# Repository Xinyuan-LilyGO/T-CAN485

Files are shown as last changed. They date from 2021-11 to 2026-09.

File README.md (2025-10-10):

<!--
 * @Description: None
 * @version: V1.0.0
 * @Author: LILYGO_L
 * @Date: 2023-09-11 16:13:14
 * @LastEditors: LILYGO_L
 * @LastEditTime: 2024-06-24 11:24:56
 * @License: GPL 3.0
-->
<h1 align = "center">T-CAN485</h1>

## **English | [中文](./README_CN.md)**

## Version iteration:
| Version | Update date |
| :---: | :---: |
| T-CAN485 | - |

## PurchaseLink

| Product | SOC |  FLASH  |  PSRAM | Link |
| :---: | :---: |:---: | :---: | :---: |
| T-CAN485 | ESP32 | 4M | - | [AliExpress](https://pt.aliexpress.com/item/1005003624034092.html)  |

## Directory
- [**English | 中文**](#english--中文)
- [Version iteration:](#version-iteration)
- [PurchaseLink](#purchaselink)
- [Directory](#directory)
- [Describe](#describe)
- [Preview](#preview)
  - [PCB board](#pcb-board)
  - [Details](#details)
- [Module](#module)
  - [1.MCU](#1mcu)
  - [2. RS485](#2-rs485)
  - [3. CAN](#3-can)
  - [4. Booster chip](#4-booster-chip)
- [QuickStart](#quickstart)
  - [Examples Support](#examples-support)
  - [Arduino](#arduino)
    - [ESP32](#esp32)
  - [firmware download](#firmware-download)
- [PinOverview](#pinoverview)
- [RelatedTests](#relatedtests)
- [FAQ](#faq)
- [Project](#project)
- [Information](#information)
- [DependentLibraries](#dependentlibraries)

## Describe

The T-CAN485 is a core board developed based on the ESP32 chip, featuring 1 CAN bus and 1 RS485 device. It supports high voltage input (5V-12V) and is equipped with a programmable WS2812 RGB LED bead. Additionally, it supports TF card functionality.

## Preview

### PCB board

<p align="center" width="100%">
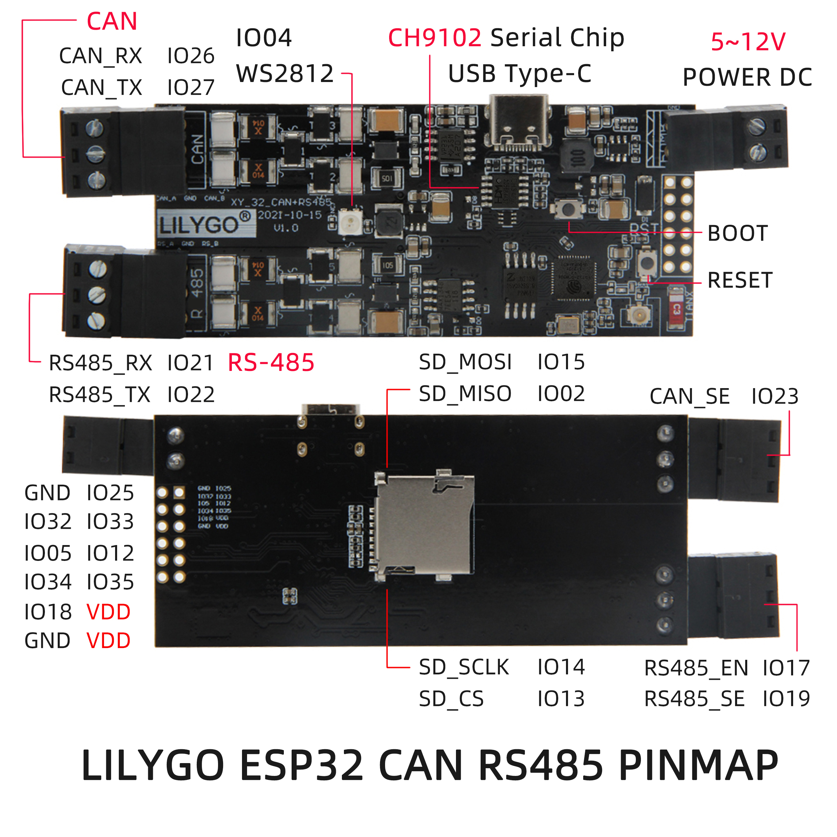
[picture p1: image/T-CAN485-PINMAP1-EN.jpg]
    
</p>

### Details

<p align="center" width="100%">
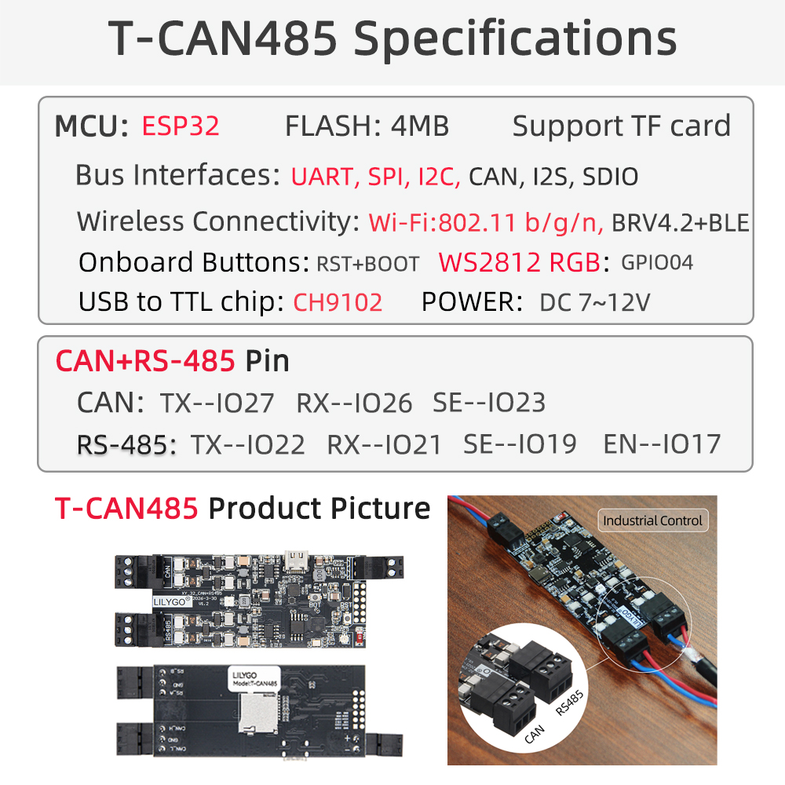
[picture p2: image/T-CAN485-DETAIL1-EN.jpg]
    
</p>

## Module

### 1.MCU

* Chip: ESP32
* FLASH: 4M
* For more details, please visit[Espressif ESP32 Datashee](https://www.espressif.com.cn/sites/default/files/documentation/esp32_datasheet_en.pdf)

### 2. RS485

* Chip: MAX13487EESA+
* Bus communication protocol: UART

### 3. CAN

* Chip: SN65HVD231
* Bus communication protocol: TWAI

### 4. Booster chip

* Chip: ME2107A50M5G

## QuickStart

### Examples Support

| Example | Support IDE And Version| Description | Picture |
| ---  | ---  | --- | --- |
| [CAN](./examples/CAN) | `[Arduino IDE][arduino_esp32_v3.0.1]` |  |  |
| [Original Test](./examples/Original_Test) |`[Arduino IDE][arduino_esp32_v3.0.1]` | Product factory original testing |  |
| [RS485_WS2812B](./examples/RS485_WS2812B) |`[Arduino IDE][arduino_esp32_v3.0.1]` |  |  |
| [SD](./examples/SD) |`[Arduino IDE][arduino_esp32_v3.0.1]` |  |  |
| [WIFI_HTTP_Download_File](./examples/WIFI_HTTP_Download_File) |`[Arduino IDE][arduino_esp32_v3.0.1]` |  |  |
| [WS2812B_Blink](./examples/WS2812B_Blink) |`[Arduino IDE][arduino_esp32_v3.0.1]` |  |  |

| Firmware | Description | Picture |
| ---  | ---  | --- |
| [Original Test V1.0.0](./firmware/[T-CAN485_V1.0][Original_Test]_firmware_V1.0.0) | Original |  |

### Arduino
1. Install[Arduino](https://www.arduino.cc/en/software),Choose installation based on your system type.

2. Open the "example" directory within the project folder, select the example project folder, and open the file ending with ".ino" to open the Arduino IDE project workspace.

3. Open the "Tools" menu at the top right -> Select "Board" -> "Board Manager." Find or search for "esp32" and download the board files from the author named "Espressif Systems." Then, go back to the "Board" menu and select the development board type under "ESP32 Arduino." The selected development board type should match the one specified in the "platformio.ini" file under the [env] section with the header "board = xxx." If there is no corresponding development board, you may need to manually add the development board from the "board" directory within your project folder.

4. Open menu bar "[File](image/6.png)" -> "[Preferences](image/6.png)" ,Find "[Sketchbook location](image/7.png)"  here,copy and paste all library files and folders from the "lib" folder in the project directory into the "libraries" folder in this directory.

5. Select the correct settings in the Tools menu, as shown in the table below.

#### ESP32
| Setting | Value |
| :---: | :---: |
| Board | ESP32 Dev Module |
| Upload Speed | 921600 |
| CPU Frequency | 240MHz (WiFi) |
| Flash Mode | QIO |
| Flash Size | 4MB (32Mb) |
| Core Debug Level | None |
| PSRAM | Disable |
| Arduino Runs On | Core 1 | 

6. Select the correct port.

7. Click "<kbd>[√](image/8.png)</kbd>" in the upper right corner to compile,If the compilation is correct, connect the microcontroller to the computer,Click "<kbd>[→](image/9.png)</kbd>" in the upper right corner to download.

### firmware download
1. Open the project file "tools" and locate the ESP32 burning tool. Open it.

2. Select the correct burning chip and burning method, then click "OK." As shown in the picture, follow steps 1->2->3->4->5 to burn the program. If the burning is not successful, press and hold the "BOOT-0" button and then download and burn again.

3. Burn the file in the root directory of the project file "[firmware](./firmware/)" file,There is a description of the firmware file version inside, just choose the appropriate version to download.

<p align="center" width="100%">
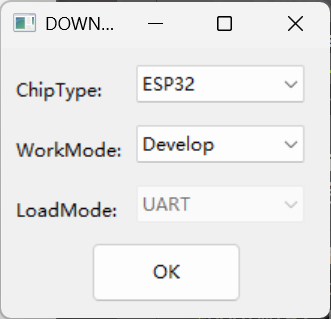
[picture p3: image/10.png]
    
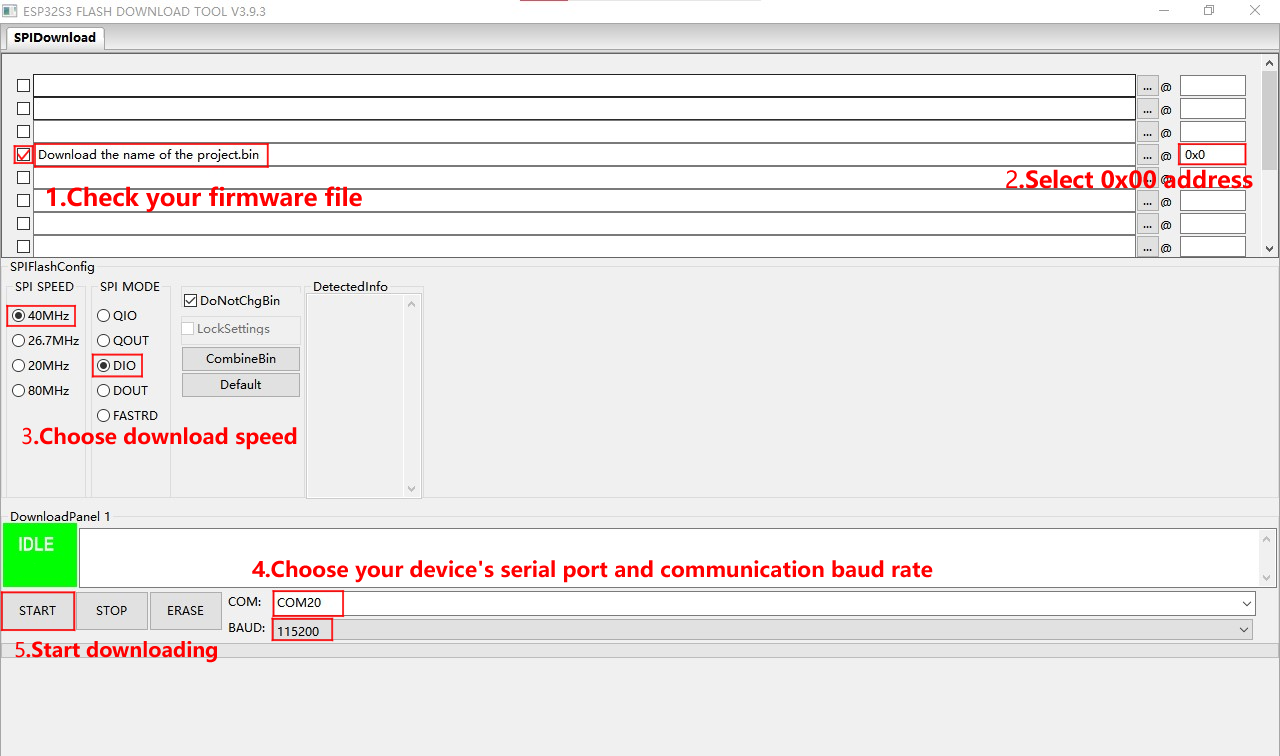
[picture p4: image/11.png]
    
</p>

## PinOverview

| RS485 PIN  | ESP32 PIN|
| :---: | :---:|
| TX | IO22 |
| RX | IO21 |
| CALLBACK | IO17 |
| EN | IO9 |

| WS2812 PIN  | ESP32 PIN|
| :---: | :---:|
| DATA | IO4 |

| ME2107 PIN  | ESP32 PIN|
| :---: | :---:|
| EN | IO16 |

| SD PIN  | ESP32 PIN|
| :---: | :---:|
| MISO | IO2 |
| MOSI | IO15 |
| SCLK | IO14 |
| CS | IO13 |

## RelatedTests

## FAQ

* Q. After reading the above tutorials, I still don't know how to build a programming environment. What should I do?
* A. If you still don't understand how to build an environment after reading the above tutorials, you can refer to the [LilyGo-Document](https://github.com/Xinyuan-LilyGO/LilyGo-Document) document instructions to build it.

<br />

* Q. Why does Arduino IDE prompt me to update library files when I open it? Should I update them or not?
* A. Choose not to update library files. Different versions of library files may not be mutually compatible, so it is not recommended to update library files.

<br />

* Q. Why is my board continuously failing to download the program?
* A. Please hold down the "BOOT-0" button and try downloading the program again.

## Project
* [T-CAN485](./project/T-CAN485.pdf)

## Information
* [MAX13487EESA+](./information/MAX13487EESA+.pdf)
* [SN65HVD231](./information/SN65HVD231.pdf)

## DependentLibraries
* [FastLED-3.7.0](https://github.com/FastLED/FastLED)

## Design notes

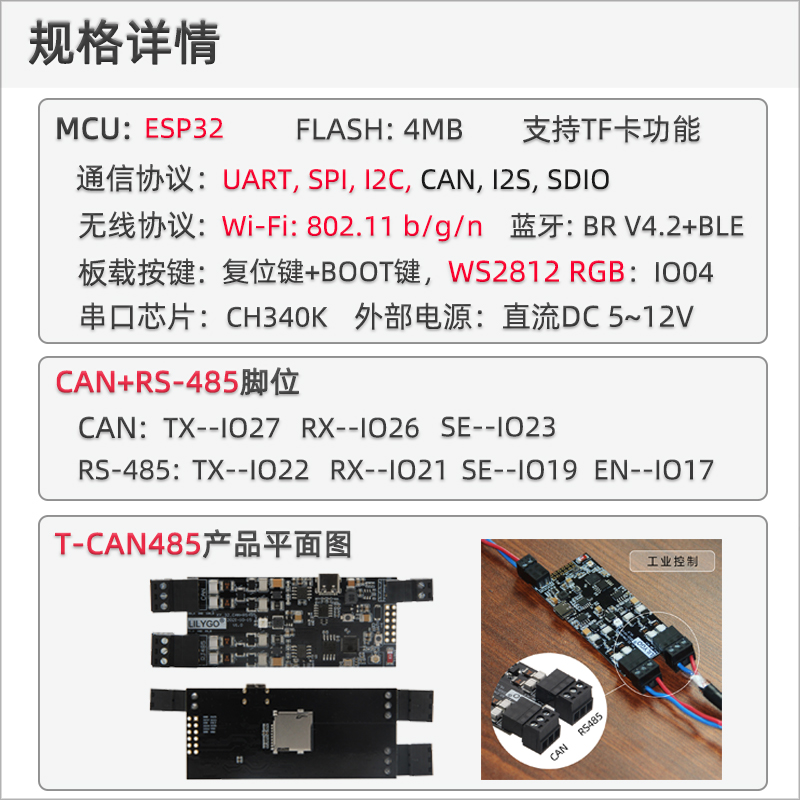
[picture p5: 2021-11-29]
image/T-CAN485-DETAIL-CN.jpg

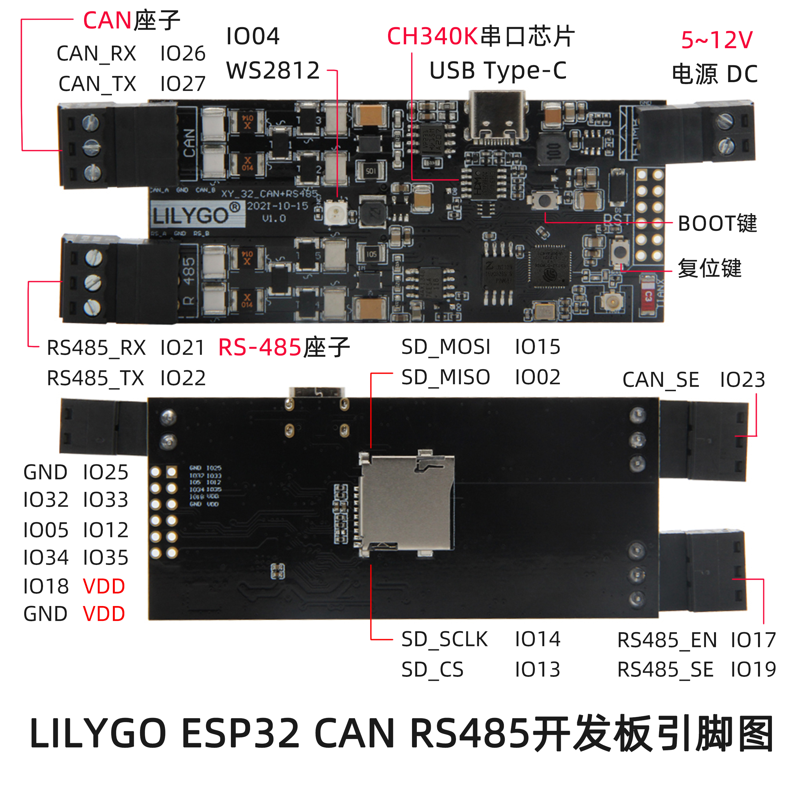
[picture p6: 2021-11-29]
image/T-CAN485-PINMAP-CN.jpg

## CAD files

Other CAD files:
project/T-CAN485.dwg

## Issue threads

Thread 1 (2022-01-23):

Documentation: Wrong URL in README.md for Arduino Board install

milen100, 2022-01-23:
URL should be fixed to : https://raw.githubusercontent.com/espressif/arduino-esp32/gh-pages/package_esp32_index.json .
In the REAME.md now there is missing slash which cases URL access to fail when the URL is added in Arduino Preferences page.

Roman-Jordan, 2022-01-23:
Good call on this, It would be nice to identify procedures to load ones software on the module.
  * Press and hold `reset` and `boot` button.
  * Release the `Reset` button, and then the `boot` button.

LilyGO, 2022-01-24:
Thank you for your suggestion

Roman-Jordan, 2022-01-28:
Are you using PlatformIO? I use the esp32 one..

crow1170, 2022-01-28:
I'm trying to use the Arduino IDE, and while an Esp32 Dev board exists, it's throwing an error in the compile step:

> In file included from c:\$$$\documents\arduinodata\packages\esp32\tools\xtensa-esp32-elf-gcc\gcc8_4_0-esp-2021r2\xtensa-esp32-elf\include\c++\8.4.0\memory:63,
                 from C:\$$$\Documents\ArduinoData\packages\esp32\hardware\esp32\2.0.2\cores\esp32\Esp.cpp:24:
c:\$$$\documents\arduinodata\packages\esp32\tools\xtensa-esp32-elf-gcc\gcc8_4_0-esp-2021r2\xtensa-esp32-elf\include\c++\8.4.0\bits\allocator.h:46:10: fatal error: bits/c++allocator.h: No such file or directory
 #include <bits/c++allocator.h> // Define the base class to std::allocator.
          ^~~~~~~~~~~~~~~~~~~~~
compilation terminated.
exit status 1
Error compiling for board ESP32 Dev Module.

I expected the Boards Manager would have prevented such an error, but I'm not even sure that everything would work if that error is resolved.

The board doesn't behave any differently when I perform the reset/boot pattern you mentioned, except to send some text over the Serial Monitor:

> rst:0x1 (POWERON_RESET),boot:0x3 (DOWNLOAD_BOOT(UART0/UART1/SDIO_REI_REO_V2))
waiting for download

Closed 2022-01-24.

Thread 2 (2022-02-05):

modbus rs485/can to mqtt software on T-CAN485

xjustbmw, 2022-02-05:
Hi there,

I purchased the t-can485 board for the following project:

I'm trying to achieve rs485/canbus to mqtt converter over wifi ( and optional if there is the possibility to add rj45 wired lan extension to it)

Anybody can help me with this software ? Should be similar to Friendtrol's GW-1205B interface.
Read/write a few registers over mqtt protocol. Config the initial wifi credentials in AP mode.

Im interested in buying at least 200 boards like this if the software works.
I can also support this software development if necessary.

Many thanks,
Adrian

Roman-Jordan, 2022-02-05:
That does not sound to difficult 🤔 .. Fork and drop me an invite.

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

Roman-Jordan, 2022-02-06:
As this does not seem to be an issue with the board. Would you mind closing this and opening it up in a fork?

Closed 2022-02-06.

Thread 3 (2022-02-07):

Arduino IDE set up

antoineTK, 2022-02-07:
Hi team!

I wanted to make sure I was doing the right things setting the Arduino IDE

1- As described in readme file: add https://raw.githubusercontent.com/espressif/arduino-esp32/gh-pages/package_esp32_index.json

2- Restart IDE

3- In board manager look up esp32 and download latest version of esp32 by Espressif Systems

4- When building and uploading choose "ESP32 Arduino --> ESP32-Dev Module"

antoineTK, 2022-02-07:
If I do it this way and I try building "Freenove_WS2812_Lib_for_ESP32" example sketches I get

In file included from C:\Users\Antoine\Documents\Arduino\libraries\Freenove_WS2812_Lib_for_ESP32\examples\Rainbow\Rainbow.ino:1:
C:\Users\Antoine\Documents\Arduino\libraries\Freenove_WS2812_Lib_for_ESP32\src/Freenove_WS2812_Lib_for_ESP32.h:35: warning: "RMT_DEFAULT_CONFIG_TX" redefined
 #define RMT_DEFAULT_CONFIG_TX(gpio, channel_id)      \

In file included from C:\Users\Antoine\Documents\Arduino\libraries\Freenove_WS2812_Lib_for_ESP32\src/Freenove_WS2812_Lib_for_ESP32.h:18,
                 from C:\Users\Antoine\Documents\Arduino\libraries\Freenove_WS2812_Lib_for_ESP32\examples\Rainbow\Rainbow.ino:1:
C:\Users\Antoine\AppData\Local\Arduino15\packages\esp32\hardware\esp32\2.0.2/tools/sdk/esp32/include/driver/include/driver/rmt.h:87: note: this is the location of the previous definition
 #define RMT_DEFAULT_CONFIG_TX(gpio, channel_id)      \

In file included from C:\Users\Antoine\Documents\Arduino\libraries\Freenove_WS2812_Lib_for_ESP32\src\Freenove_WS2812_Lib_for_ESP32.cpp:12:
C:\Users\Antoine\Documents\Arduino\libraries\Freenove_WS2812_Lib_for_ESP32\src\Freenove_WS2812_Lib_for_ESP32.h:35: warning: "RMT_DEFAULT_CONFIG_TX" redefined
 #define RMT_DEFAULT_CONFIG_TX(gpio, channel_id)      \

In file included from C:\Users\Antoine\Documents\Arduino\libraries\Freenove_WS2812_Lib_for_ESP32\src\Freenove_WS2812_Lib_for_ESP32.h:18,
                 from C:\Users\Antoine\Documents\Arduino\libraries\Freenove_WS2812_Lib_for_ESP32\src\Freenove_WS2812_Lib_for_ESP32.cpp:12:
C:\Users\Antoine\AppData\Local\Arduino15\packages\esp32\hardware\esp32\2.0.2/tools/sdk/esp32/include/driver/include/driver/rmt.h:87: note: this is the location of the previous definition
 #define RMT_DEFAULT_CONFIG_TX(gpio, channel_id)      \

In file included from C:\Users\Antoine\Documents\Arduino\libraries\Freenove_WS2812_Lib_for_ESP32\src\Freenove_WS2812_Lib_for_ESP32.cpp:12:
C:\Users\Antoine\Documents\Arduino\libraries\Freenove_WS2812_Lib_for_ESP32\src\Freenove_WS2812_Lib_for_ESP32.cpp: In member function 'bool Freenove_ESP32_WS2812::begin()':
C:\Users\Antoine\Documents\Arduino\libraries\Freenove_WS2812_Lib_for_ESP32\src\Freenove_WS2812_Lib_for_ESP32.h:53:5: error: no match for 'operator=' (operand types are 'rmt_config_t' and '<brace-enclosed initializer list>')
     }
     ^
C:\Users\Antoine\Documents\Arduino\libraries\Freenove_WS2812_Lib_for_ESP32\src\Freenove_WS2812_Lib_for_ESP32.cpp:26:11: note: in expansion of macro 'RMT_DEFAULT_CONFIG_TX'
  config = RMT_DEFAULT_CONFIG_TX(pin, rmt_chn);
           ^~~~~~~~~~~~~~~~~~~~~
In file included from C:\Users\Antoine\Documents\Arduino\libraries\Freenove_WS2812_Lib_for_ESP32\src\Freenove_WS2812_Lib_for_ESP32.h:18,
                 from C:\Users\Antoine\Documents\Arduino\libraries\Freenove_WS2812_Lib_for_ESP32\src\Freenove_WS2812_Lib_for_ESP32.cpp:12:
C:\Users\Antoine\AppData\Local\Arduino15\packages\esp32\hardware\esp32\2.0.2/tools/sdk/esp32/include/driver/include/driver/rmt.h:81:3: note: candidate: 'rmt_config_t& rmt_config_t::operator=(const rmt_config_t&)'
 } rmt_config_t;
   ^~~~~~~~~~~~
C:\Users\Antoine\AppData\Local\Arduino15\packages\esp32\hardware\esp32\2.0.2/tools/sdk/esp32/include/driver/include/driver/rmt.h:81:3: note:   no known conversion for argument 1 from '<brace-enclosed initializer list>' to 'const rmt_config_t&'
C:\Users\Antoine\AppData\Local\Arduino15\packages\esp32\hardware\esp32\2.0.2/tools/sdk/esp32/include/driver/include/driver/rmt.h:81:3: note: candidate: 'rmt_config_t& rmt_config_t::operator=(rmt_config_t&&)'
C:\Users\Antoine\AppData\Local\Arduino15\packages\esp32\hardware\esp32\2.0.2/tools/sdk/esp32/include/driver/include/driver/rmt.h:81:3: note:   no known conversion for argument 1 from '<brace-enclosed initializer list>' to 'rmt_config_t&&'
exit status 1
Erreur de compilation pour la carte ESP32 Dev Module

Roman-Jordan, 2022-02-07:
I have no idea at this moment but might be able to poke at it a bit later
today. Gotta get in the line for the homeless shelter early if a want a
place to stay.. so.. we shall see if I get time. Hahaha, your only valuable
in america if you do drugs and have kids. But if you spend your time
learning skills that no one understands.. you deserve to be homeless cause
your less than poop.

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

Roman-Jordan, 2022-02-07:
Sorry, just woke up when I had seen this. I will have some time this
evening sometime to poke at this if you want.

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

antoineTK, 2022-02-07:
No worries man, I hope your day is going ok!

I was thinking I might use FastLED if I can not figure this out

Roman-Jordan, 2022-02-07:
Nice. If you got time for a call. I can walk you through it.

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

Roman-Jordan, 2022-02-07:
42427257fourTwo Drop me a text when your ready.

LilyGO, 2022-02-09:
Hello, it can be seen from the log that the WS2812 library is not installed;
1) First compile the flash program from the example to test whether the basic environment is completed.
2) Install all required dependencies
- https://github.com/Freenove/Freenove_WS2812_Lib_for_ESP32
- https://github.com/miwagner/ESP32-Arduino-CAN

antoineTK, 2022-02-09:
The library was installed but I was getting it from the T-CAN485 repo. Getting it from the repo you linked worked for me, thank you!

In the board selection, can you confirm the default parameters are correct?

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

antoineTK, 2022-02-09:
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

LilyGO, 2022-02-10:
There is no problem with your parameter settings.

LilyGO, 2022-02-10:
FLASH MODE please select DIO

antoineTK, 2022-02-14:
@LilyGO any ideas?

Closed 2022-02-09.

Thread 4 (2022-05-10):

CAN bus continuously publishes and blocks the programme

raul-riera-imatia, 2022-05-10:
Hello, good morning!

I have a problem with the CAN bus.
I'm trying the example code found in example/Arduino/CAN
Although the bus should publish at 1000ms intervals, the bus publishes continuously and blocks the program. It never reaches line 89.
Can you help me? Do you know what is wrong?

Thank you very much for your help.

LilyGO, 2022-09-05:
There may be failures caused by unsuccessful sending. It is recommended that you try connecting the cable before powering on.

dalathegreat, 2023-04-02:
For anyone still having issues with CAN, I have a repository set up here that uses both CAN and Modbus RTU at the same time on the LilyGo Hardware: https://github.com/dalathegreat/BYD-Battery-Emulator-For-Gen24

Closed 2024-07-10.

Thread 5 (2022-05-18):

Tutorial

hanusek, 2022-05-18:
Hello.
I bought LILYGO ESP32 CAN RS485 and take it from the box. I would like to upload to it an example program but I haven't any information. I need a basic tutorial - on how to get started.
I have a problem. Arduino IDE did not recognize the T-CAN485 board (VID: 1A86 PID: 7522).

LilyGO, 2022-06-27:
1. Install ESP32 board support
2. Connect the USB, select the port
3. Click Upload

newdamage1, 2024-07-20:
It is more complicated than three steps. The Arduino IDE asks for the board; This board is not listed as an option, esp32 selections error about missing files.

We don't expect a step-by-step for beginners, but your effort at decent documentation would be appreciated by those who spend money on your products.

danishzd, 2025-07-08:
I am having trouble setting up one that I just bought, My computer does not detect any hardware connection and the board has rapidly switching lights when its plugged in. What am i missing?

lewisxhe, 2025-07-09:
Is the CH9102 driver installed? You should be able to see a COM device in the Windows Device Manager.

lewisxhe, 2025-07-09:
Is it convenient to shoot a video?
, the steps are as follows:
1. Open the computer device manager
2. Insert the USB
3. Check if there is a device in the Port list

lewisxhe, 2025-07-09:
Device Manager doesn't even respond? Refreshing the device doesn't work?

danishzd, 2025-07-09:
No, strangely it doesn’t do a thing, not even a sound

lewisxhe, 2025-07-10:
OK. Then it is damaged. Normally it will recognize the USB and see the USB device in the device manager. If you have just purchased it, please contact the dealer for after-sales service!

lewisxhe, 2025-07-15:
I have received your video and I have already talked to them. They should have arranged the shipment for you.

Closed 2022-06-27.

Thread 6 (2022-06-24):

USB Type-C Connection didn't see from Arduino-IDE Ports

Peerahongw, 2022-06-24:
Dear everyone,

How can I communicate or upload program from Arduino-IDE?

Thanks

LilyGO, 2022-06-27:
1. Install ESP32 board support
2. Connect the USB, select the port
3. Click Upload

Closed 2022-06-27.

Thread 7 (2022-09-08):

[CAN] Example for Arduino not working

hanusek, 2022-09-08:
Hello @LilyGO
I have two TTGO T-CAN485 boards (v1.0 and v1.1).
I'm trying to run the [canbus](https://github.com/Xinyuan-LilyGO/T-CAN485/tree/main/example/Arduino/CAN) example. But I have a problem with it. The Board not sends and receive any can bus frames. I have only `TIME -> CAN send done` in the serial-log.

1.
I found weird things in the schematic and [code](https://github.com/Xinyuan-LilyGO/T-CAN485/blob/07886ab0acd5bdf81f059a37994451682eaa761b/example/Arduino/CAN/config.h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).
**CAN_TX in the schematic == GPIO27
CAN_RX in the schematic == GPIO26**
but in **config.h**:
```
#define CAN_TX_PIN 26
#define CAN_RX_PIN 27
```
It is a bug?

2. I connect my board to the USB port (power + data).
Did the board require a power supply to work (5 VDC)?
Because in example code we have it:
```
pinMode(PIN_5V_EN, OUTPUT);
digitalWrite(PIN_5V_EN, HIGH);
```

Please help.

LilyGO, 2022-09-09:
Try using this example.

`https://github.com/Xinyuan-LilyGO/T-CAN485/tree/main/example/PlatfromIO/CAN`
The thing to pay attention to is whether the chip is a V3 version. Q&A in the readme suggests that there is a register that needs to be modified. The modified place is
`https://github.com/Xinyuan-LilyGO/T-CAN485/blob/07886ab0acd5bdf81f059a37994451682eaa761b/example/PlatfromIO/CAN/lib/ESP32-Arduino-CAN/src/CAN.c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`

Closed 2022-09-26.

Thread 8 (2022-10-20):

RS485 pin layout unclear + antennae interface

mortennlund, 2022-10-20:
Its not immediately clear whats the port layout of the RS485 connector A and B (or CAN for that matter). See image:
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

Also what antennae interface is used? MHF3 or MHF4?
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

Best Morten

LilyGO, 2022-10-24:
The middle interface is GND. You try to connect A to the following port. B continues above. Reverse it if communication fails.
The place in the red circle in this picture is the external antenna. Can not be used.
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

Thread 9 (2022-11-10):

Error in config.h from can.ino example

MENIER, 2022-11-10:
Hello,
It seems to have an error in your example :(https://github.com/Xinyuan-LilyGO/T-CAN485/tree/main/example/Arduino/CAN) in config.h:
```
#define CAN_TX_PIN 26
#define CAN_RX_PIN 27
```
and in CAN.ino
```
CAN_cfg.tx_pin_id = GPIO_NUM_27;
CAN_cfg.rx_pin_id = GPIO_NUM_26;
```

Llgok, 2024-06-24:
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

Please use the latest version branch Arduino_ESP32_v3.0.1 as the main reference.

Closed 2024-06-24.

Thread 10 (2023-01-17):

missing documentation wifi connector

wiensmit, 2023-01-17:
i can't find this anywhere in the documentation, what type of mhf connector fits this board for the wifi antenna.

Rojasoterom, 2024-01-06:
> i can't find this anywhere in the documentation, what type of mhf connector fits this board for the wifi antenna.

Do you find it? I try but i can't

HBK1, 2024-01-06:
External wifi antenna can not be used.
Se https://github.com/Xinyuan-LilyGO/T-CAN485/issues/8#issuecomment-1288286752

Closed 2024-07-10.

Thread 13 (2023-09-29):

Problem with uploading application when inputs/outputs are connected

balouken, 2023-09-29:
What is the best way to program this board while everything is connected?
Some Reset/boot button procedure? I've tested some stuff, but don't have success

Llgok, 2024-07-10:
@balouken
Please specifically describe the problem you encountered (serial port output or programming upload error log).

Closed 2024-08-21.

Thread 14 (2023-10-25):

Expected usage of the bus GND pins?

bobemoe, 2023-10-25:
The middle pins of the CAN and RS485 bus connectors are labelled AGND and DGND respectively on the schematic and are not connected directly to GND. It appears they connect to GND through a RC filter of some sort and are also connected to the transient voltage suppression components respectively for each bus.

What is the expected use of this pin. I cant work out if:

1. Is this pin REQUIRED to be connected to external ground for the voltage protection components to work properly or could it be left unconnected?
2. Is this is a suitable GND point to connect the shield of the bus cables to. I understand the shield should be connected directly to ground and only at one end of the bus. This would be a very convenient location but given that its not directly connected to GND and I cant find any documentation on this pin, I'm unsure if this is a correct use.

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
https://github.com/Xinyuan-LilyGO/T-CAN485/blob/main/doc/schematic.pdf

bobemoe, 2024-02-14:
Another possibility here would be, when connecting to an OBD port which has 2 ground pins, signal and chassis:
The signal ground would connect to the middle GND pin along with the CAN hi/low lines, and the chassis ground would connect to the power GND along with the supply voltage line?
I guess then the shield would connect to `chassis ground`.

Really if one of the designers of this board, or someone experienced in this, could shed some light on the intention of these middle GND pins that would be really helpful. Thanks.

Llgok, 2024-06-24:
> Another possibility here would be, when connecting to an OBD port which has 2 ground pins, signal and chassis: The signal ground would connect to the middle GND pin along with the CAN hi/low lines, and the chassis ground would connect to the power GND along with the supply voltage line? I guess then the shield would connect to chassis ground.
>
> Really if one of the designers of this board, or someone experienced in this, could shed some light on the intention of these middle GND pins that would be really helpful. Thanks.

AGND is used for the anti-static shielded ground interface of the CAN bus. DGND is used for the anti-static shielded ground interface of the RS485. The function of the two GNDs is to prevent static electricity and protect the circuit board.
@bobemoe

Closed 2024-06-24.

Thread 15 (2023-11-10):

How to change IER parameter of CAN controller?

ajaykoppisetty, 2023-11-10:
I got the chip with v3. In the read me file, it was mentioned to update the IER parameter for v3 for CAN bus to work. How and where to change it? Please help.

aliman22, 2024-01-18:
by hans from https://www.cnx-software.com/2021/12/20/ttgo-t-can485-an-esp32-board-with-rs485-can-bus-interfaces/
Just to save someone else 3 hours of googling trying to figure out what this cryptic instruction actually means:

Depending on the ESP32 chip, the CAN controller register IER parameter needs to be changed. If it is a V3 version chip, you can use 0xEF, otherwise, use 0xFF.

You can change the value from 0xef to 0xff on line 229 of the file CAN.c in the ESP32-Arduino-CAN library:

MODULE_CAN->IER.U = 0xef; //ESP32 V3 0XEF    ESP32 NOT V3 0XFF

Do note it is set to 0xef by default, so if you have a V3 ESP32 you do not need to change anything.

Closed 2024-07-10.

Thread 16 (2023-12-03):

RS485 ESPHome connect issue

Yocee84, 2023-12-03:
Hi! I cant use this panel. Please share correct esphome setup.

I use this:

substitutions:
  devicename: *******
  description: ********
  entity_prefix: *******

esphome:
  name: "${devicename}"
  comment: "${description}"

esp32:
  board: esp32dev
  framework:
    type: arduino

# Enable logging
logger:
  level: DEBUG
  baud_rate: 0

web_server:
  port: 80

# Enable Home Assistant API
api:
  encryption:
    key: "*****************************************"

ota:

wifi:
  networks:
  - ssid: !secret wifi_ssid
    password: !secret wifi_password
  - ssid: *********
    password: ************
  reboot_timeout: 0.05h

  # Enable fallback hotspot (captive portal) in case wifi connection fails
  ap:
    ssid: "*****2"
    password: "**********"

captive_portal:

light:
  - platform: neopixelbus
    type: GRB
    variant: WS2812
    pin: GPIO04
    num_leds: 1
    name: "Light"

uart:
  id: mod_bus
  tx_pin: 22
  rx_pin: 21
  baud_rate: 9600
  stop_bits: 1

modbus:
  flow_control_pin: 5
  id: heatpump_modbus

Bwooce, 2023-12-09:
Try this for some inspiration, I'm working on a homeassistant forum post to go with it. This is working for my application.

https://gist.github.com/Bwooce/7c43622dcc9bc1fbb04d7a0f1e5528df

Yocee84, 2023-12-12:
> Try this for some inspiration, I'm working on a homeassistant forum post to go with it. This is working for my application.
>
> https://gist.github.com/Bwooce/7c43622dcc9bc1fbb04d7a0f1e5528df

That's how it works for me. Thank you very much!
You should get a commission. Is there a buy me a coffee link?

Saentist, 2023-12-29:
This is how I make it to work in ESPHome with Growatt inverter

`Output` section is important obviously, without it it not work.

```yaml
# Set pins required for LilyGo T-CAN485 board
output:
  - platform: gpio
    id: ENABLE_PIN # Enable the chip
    pin:
      number: GPIO19
      inverted: true
  - platform: gpio
    id: SE_PIN # Enable autodirection
    pin:
      number: GPIO17
      inverted: true
  - platform: gpio
    id: ENABLE_5V_PIN # Enable 5V pin for RS485 chip
    pin:
      number: GPIO16
      inverted: true

# UART MODBUS configuration entry
uart:
  id: mod_uart
  rx_pin: GPIO21
  tx_pin: GPIO22
  baud_rate: 9600 # The out-of-box baud rate for my particular sensor->RS485 bridge
  stop_bits: 1
  parity: NONE
#  data_bits: 8
  debug:
    direction: BOTH
    dummy_receiver: false
    after:
      delimiter: "\n"
    sequence:
      - lambda: UARTDebug::log_string(direction, bytes);

modbus:
  id: modbus1
  uart_id: mod_uart
#  flow_control_pin: GPIO4

modbus_controller:
  - id: Growatt_MIN600TLX
    address: 0x1   ## address of the ModBUS slave device on the bus
    modbus_id: modbus1
    setup_priority: -10
```

drawlusyk, 2024-05-22:
[Archive.zip](https://github.com/Xinyuan-LilyGO/T-CAN485/files/15409245/Archive.zip)

Here are my can1 and can2 files. Connect h to h and l to l. Sends test data back and forth.

dvbit, 2024-11-01:
Just. Ought one device. I have a doubt about the connections. As far as I know a b and gnd are needed.in the board Iconnector I see just an and b on pin 20 and 21 . Where is gnd?

Sleeper85, 2025-01-11:
> Here are my can1 and can2 files. Connect h to h and l to l. Sends test data back and forth.

Thanks for sharing your examples, so you confirmed that it is necessary to enable (set to high) PIN 23 to make the CAN chip work ?

Llgok, 2025-01-13:
@Sleeper85
For using CAN, you can refer to this example：[CAN](https://github.com/Xinyuan-LilyGO/T-CAN485/blob/arduino-esp32-libs_v3.0.1/examples/CAN/CAN.ino)
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

Sleeper85, 2025-01-16:
@Llgok

Thanks this info really helped me and it works fine with ESPHome and these settings for RS485 and CAN.

```YAML
# +--------------------------------------+
# | LilyGo T-CAN485 related config       |
# +--------------------------------------+

output:
  # MAX13487E SHDN (enable RS485 chip)
  - platform: gpio
    id: RS485_SE
    pin:
      number: 19
      inverted: true # set HIGH level
  # MAX13487E RE (enable RS485 autodirection)
  - platform: gpio
    id: RS485_EN
    pin:
      number: 17
      inverted: true # set HIGH level
  # RS485 and CAN Boost power supply
  - platform: gpio
    id: CGQ_EN
    pin:
      number: 16
      inverted: true # set HIGH level
  # SN65HVD231DR RS PIN (CAN high speed mode)
  - platform: gpio
    id: CAN_SE
    pin:
      number: 23
      inverted: false # set LOW level
```

Closed 2024-07-10.

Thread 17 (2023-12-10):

Request: Docs/silkscreen for power connection noting GND/-ve is on the board edge

Bwooce, 2023-12-10:
There's not a lot of visible guidance on the T-CAN485 board for the power connection, and so I assumed you'd made it idiot proof and put it through a bridge rectifier. Yes I know, "[always read the data sheet](https://github.com/Xinyuan-LilyGO/T-CAN485/blob/main/doc/schematic.pdf)"...

It survived a reverse-polarity event due to your other good design decisions but the board silkscreen writing is obscured once the components are placed e.g. I can't read them on the delivered board, although now I *know* it says GND I can kinda read it and not OOO. So can you please:
1. Either silkscreen the bottom with the power pin polarity, or move the words out into the square in front of the connector?
2. Update your graphics showing the pins and connections to show where +ve/-ve are on these power connectors.

It would also probably be enlightening for some buyers to know these are all plugs and sockets, I thought they were weird screw connectors until I got it and looked closely. I like it, it just wasn't obvious.

lewisxhe, 2024-02-19:
Hi,

Thank you for your feedback, I have reported it to LilyGo

Closed 2024-07-10.

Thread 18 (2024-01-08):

TF Card Read/Write Documentation

Rojasoterom, 2024-01-08:
Hi, i have problems making TF Card works. I'm trying to use RS485 and SD but when i use SD.begin, RS485 data was not readed.

Lastly, i try the following program to use only TF card. But without connect to the card:

```
#include <SD.h>
#include <SPI.h>

File myFile;

void setup()
{
  Serial.begin(9600);
  Serial.print("Iniciando SD ...");
  if (!SD.begin(13)) {
    Serial.println("No se pudo inicializar");
    return;
  }
  Serial.println("inicializacion exitosa");

  myFile = SD.open("archivo.txt");//abrimos  el archivo
  if (myFile) {
    Serial.println("archivo.txt:");
    while (myFile.available()) {
    	Serial.write(myFile.read());
    }
    myFile.close(); //cerramos el archivo
  } else {
    Serial.println("Error al abrir el archivo");
  }
}

void loop()
{

}
```

Rojasoterom, 2024-01-08:
After few test, for me is works using mySD and the following begin:

```
  if (!SD.begin(13,15,2,14)) {            //T1:13,15,2,14  T2: 23,5,19,18 M5：4,23,19,18 uint8_t csPin, int8_t mosi, int8_t miso, int8_t sck
      Serial.println("initialization failed!");
      return;
    }
    Serial.println("initialization done.");
```

Closed 2024-01-08.

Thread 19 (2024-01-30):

Unusual voltage levels on RS485

bobemoe, 2024-01-30:
# Issue

We've been using these lilygo successfully for a while now using both CAN and RS232 IO and have working firmware communicating with other devices on the RS485 bus.

We've just invested in a load more of these but cant get any of them communicate using the known working firmware on our known working RS485 bus.

To diagnose we hooked up the A and B lines to the oscilloscope, and observe unusual voltage levels.

# Expected Behaviour:

This is taken from other devices communicating on the modbus, as expected, when idle both lines are near 0. When data they are inverted square signal of each other going up to about 3.3v.

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

# Actual Behaviour:

This is taken from the output of the lilygo. Seems the idle state voltage levels are high (both about 3V), and during data transmission, one line exhibits a voltage level that is not typical for RS-485 standards going up, it seems offset, and the signals never actually invert.

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

# Steps to Reproduce:

Programme lilygo to output data on the RS232 and monitor the voltage levels on both lines during idle and transmission states using a oscilloscope.

# Additional Info

Unfortunately all our original working lillygo are out in the field so we can't make a direct comparison of these ones to our known working ones.

If we connect both lines to the logic analizer then we only see data on one line, as the yellow trace above is just detected as high. I know during development with the original boards we used the logic analizer extensively and both lines were detected.

Has something changed? We've tried adding/changing termination and biasing resistors with no luck.

We have 20 of these and have tested about 5 so far all exhibiting same issue. I believe they are genuine units. Can we provide batch number or further details?

lewisxhe, 2024-02-03:
Hi @bobemoe

Can you use two T-CAN485 for transceiver loopback testing?
First check whether the hardware can work normally?
I noticed that you said the idle voltage is about 3V. Did you measure this by connecting it to another bus or not?

bobemoe, 2024-02-03:
@lewisxhe Thanks for your response. I am in the workshop Tuesday so will test two T-CAN485 then.

Idle voltage of about 3V is shown on the "Actual" traces above. It was measured directly from the RS485 pins on the lilygo with no bus connected. Similarly the "Expected" trace was taken from the RS485 pins on one of our devices (uses MAX3486 transceiver) with no bus connected. It would be interesting to observe the voltages when the bus is connected between the two devices. I will post the traces of this on Tuesday.

bobemoe, 2024-02-08:
We managed to get one of our original lilygos back from the field which game me something to compare to.

The originals are v1.0 and the new ones we have are v1.1.

I made a small test program outputting on rs495 and uploaded to both, there was a difference between the outputs on both boards, until I set PIN_5V_EN to HIGH.

Not sure why this was not needed on the old ones or what it does exactly. Not even 100% sure it was definitely the fix as we compared and changed a lot of things over the coarse of testing, but this was the only difference between the boards we observed.

Anyway the end result is we now have them working!

Is there any change logs for 1.0 to 1.1? Or any docs what PIN_5V_EN high does?

lewisxhe, 2024-02-19:
Hi, @bobemoe

thanks for your feedback

1. PIN_5V_EN is actually connected to the enable port of the ME2107A50M5G DC booster. It must be set to HIGH to power CAN and RS485.

2. I asked the designer about the difference between Rev1.0 and Rev1.1. Only the input power switching circuit was changed, and other changes were not made.

3. If 1.0 does not require the additional setting of PIN_5V_EN to HIGH, then it may be different from the previous version in that the default on state when using USB power supply is removed (this is just my confirmation based on the previous circuit of the designer who designed this PCB , as this is the case on most boards).

Closed 2024-06-24.

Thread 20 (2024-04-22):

CAN485 ESPHome using CAN

drawlusyk, 2024-04-22:
Does anyone have suggestions on using 2 CAN485 connected vi can h & l.
I have used mcp2515 in esphome successfully but can not get these working. I have them flashed and blinking the led but not send/receive of can messages between the two.
I have wires from h to h and l to l. Is any termination required?

`time:
  - platform: sntp
    on_time:
      - seconds: /5
        then: #trying variations
          - canbus.send:
              data: [0x09, 0x10, 0x11, 0x12, 0x13, 0x14, 0x15, 0x16]
          - canbus.send:
              can_id: 2
              data: [0x01, 0x02, 0x03, 0x04, 0x05, 0x06, 0x07, 0x08]
          - canbus.send: [ 0x11, 0x22, 0x33 ]    `

`canbus:
  - platform: esp32_can
    tx_pin: GPIO27
    rx_pin: GPIO26
    can_id: 1 #the second device is can_id 2
    bit_rate: 1000kbps #have also tried 250kbps
    on_frame:
    - can_id: 0 #have tried 0 as well as 1/2 for accepting from the other device
      can_id_mask: 0
      use_extended_id: false
      then:
      - lambda: |-
          std::string b(x.begin(), x.end());
          ESP_LOGD("canid 2", "%s", &b[0] );`

teunito, 2024-05-22:
Same here. Can't get CAN working with esphome and T-CAN485. My YAML looks similar to those from @drawlusyk, i'm using interval and not time.
I tried it with a 120R resistor for termination. In https://github.com/Xinyuan-LilyGO/T-CAN485/blob/main/doc/schematic.pdf on page 2 section B-2 there is a 120R resistor (RY2) between CANL and CANH. So i think there is already termination on the board? But i'm not familiar with schema drawings.

I found https://github.com/Xinyuan-LilyGO/T-CAN485/issues/16#issuecomment-1872327090 describing that Output Section is obviously. Is there something similar for CAN?

Anyone any ideas or suggestion?

Llgok, 2024-07-10:
@drawlusyk
You can refer to the code of other contributors: https://github.com/Xinyuan-LilyGO/T-CAN485/issues/16#issuecomment-2125876729

drawlusyk, 2024-07-11:
Hello. I have uploaded the code used. If this is not what you are referring to, please advise.

-Dennis

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

mackloo, 2025-02-12:
@drawlusyk Did you manage to get CAN to work with esphome?

drawlusyk, 2025-02-13:
Hello. Yes. I provided details in a previous post. Let me know if you cant find it.

-Dennis

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

teunito, 2025-02-13:
@mackloo Have a look here: [RS485 ESPHome connect issue #16](https://github.com/Xinyuan-LilyGO/T-CAN485/issues/16#top)

mackloo, 2025-02-13:
Thank you! This is probably it but now my esphome api breaks so I can't connect to it..  will test later. So you have to pull the CAN_SE pin to high if I got it correctly? I checked @drawlusyk example and copied the section about the CAN_SE PIN so that should do the trick right?

mackloo, 2025-02-14:
Solved it! For anyone else that come looking I had to put this into my .yaml file:

output:
  - platform: gpio
    id: CAN_SE
    pin:
      number: 23
      inverted: false # set LOW level

Thanks for pointing me in the right direction!

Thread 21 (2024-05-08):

How to use TF card of T-CAN485 board?

jongils, 2024-05-08:
Dear all

I'm trying to use TF card at backside of T-CAN485 board using standard library of ESP but it didn't work because this board is used unique pin map comparing standard library so could you advise me how to use TF card from this board.

jongils, 2024-05-08:
Duplicated question. I found the solution from closed issue #18 . Pin assignment should be done by GPIO number not physical pin number.

Closed 2024-05-08.

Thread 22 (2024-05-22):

how to send data from lilygo esp32 by can protocol to another lilygo esp32 by can protocol and read data on serial monitors

Abdelrahmanars91, 2024-05-22:
hello im use LILYGO esp32 can but when include library not done . this massage  Error: 13 INTERNAL: Library install failed: moving extracted archive to destination dir: library not valid

Llgok, 2024-06-24:
> hello im use LILYGO esp32 can but when include library not done . this massage Error: 13 INTERNAL: Library install failed: moving extracted archive to destination dir: library not valid

If you are using the CAN bus, switch to the arduino_esp32_v3.0.1 branch and refer to [CAN](https://github.com/Xinyuan-LilyGO/T-CAN485/blob/arduino_esp32_v3.0.1/examples/CAN/CAN.ino) example.

@Abdelrahmanars91

Closed 2024-07-10.

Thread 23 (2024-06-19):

Bluetooth turn on?

sarzyk, 2024-06-19:
Hi I have lilygo T-CAN 485 connected to my inverter Deye. It works very well.
Now I made seccond battery with jk BMS and I want to integrate it with Home Assistant.

JK BMS can connect with my phone via Bluetooth.
Is there any chance (to turn on?) communicate BMS with inverter via Bluetooth?

ThAnks

HBK1, 2024-06-19:
Check this repository: https://github.com/syssi/esphome-jk-bms

sarzyk, 2024-06-24:
Thanks. Is chance tu use the lilygo with deye inverter via modbus and jk BMS via Bluetooth in the same time?

MBRetrofit, 2025-03-30:
> Thanks. Is chance tu use the lilygo with deye inverter via modbus and jk BMS via Bluetooth in the same time?

That's the idea, to connect in the same time the battery (CAN) and the Inverter (RS485).

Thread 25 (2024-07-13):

Compile error with Arduno IDE T-CAN485

alcomys, 2024-07-13:
Hello, i want to compile the software into the Lilygo with Arduino but i got this error.

Documents\Arduino\libraries\FastLED-3.7.0\src\fastspi.h:157:23: note: '#pragma message: No hardware SPI pins defined.  All SPI access will default to bitbanged output'
  157 | #      pragma message "No hardware SPI pins defined.  All SPI access will default to bitbanged output"

Thanks

Llgok, 2024-07-22:
@alcomys
This error belongs to the FastLED-3.7.0 library and has no impact on the project compilation; it can be ignored.

Closed 2024-08-21.

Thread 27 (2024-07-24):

Factory reset TCan board

JacobsMess, 2024-07-24:
Hello, I had a working TCAN485 board but I performed a "Full Clean" in Platform IO and now when I flash firmware I no longer have wifi. the Flash states it is successful. Is there a way of restoring the TCAN485 to factory state?

Llgok, 2024-08-22:
@JacobsMess
You can upload this example [Original_Test](https://github.com/Xinyuan-LilyGO/T-CAN485/tree/arduino-esp32-libs_v3.0.1/firmware) to reset the board to factory settings.
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

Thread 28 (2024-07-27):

Compilation Error - esp_intr.h no such file or directory

nagup, 2024-07-27:
```
\Arduino\libraries\ESP32-Arduino-CAN\src\CAN.c:37:10: fatal error: esp_intr.h: No such file or directory
   37 | #include "esp_intr.h"
      |          ^~~~~~~~~~~~
compilation terminated.
exit status 1
```

Getting above error. Quite vague so was not able to determine what is actually the issue, is the header file too new, too old for this example sketch?

I have just now tried to rollback the esp32 boards by espressif to version 2.0.11. Then I commented out SD_test(); because not defined.

I am going to try replacing the initial esp_intr.h with the updated " #include "esp_intr_alloc.h" " as can be found here

**UPDATE: Cannot find the line in  CAN.c on line 37 which says #include "esp_intr.h"**

```

_esp_intr.h: No such file or directory
   37 | #include "esp_intr.h"
      |          ^~~~~~~~~~~~
compilation terminated.

exit status 1

Compilation error: esp_intr.h: No such file or directory

to overcome that error I added this to the CAN.c file:

// #include "esp_intr.h"
#include "esp_intr_alloc.h" // jimn warning depreciated #include "esp_intr.h"
```

_Originally posted by @BEMSman in https://github.com/dalathegreat/Battery-Emulator/issues/116#issuecomment-1865074235__

Llgok, 2024-07-29:
@nagup
What version of the Arduino esp32 lib are you currently using?

nagup, 2024-07-29:
> @nagup What version of the Arduino esp32 lib are you currently using?

I didn't have the Arduino library installed, only the Espressif one. I just downloaded it, restarted ArduinoIDE and tried to compile but its still failing with the same error.

I tried another example sketch which came in the zip file, called esp32can_basic, compiling it still fails with same error

Llgok, 2024-07-30:
@nagup
Arduino libraries of different versions are not compatible with each other. The "main" branch only supports Arduino lib versions below 3.0, while the "arduino-esp32-libs_v3.0.1" branch supports Arduino lib versions 3.0.1 and above. If the wrong version is selected, it will result in compilation errors.
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

Llgok, 2024-07-30:
@nagup
It looks like you want to configure and run the CAN module on the T-CAN485 device. You should try using the latest branch "arduino-esp32-libs_v3.0.1" and compile the example project [CAN](https://github.com/Xinyuan-LilyGO/T-CAN485/blob/arduino-esp32-libs_v3.0.1/examples/CAN/CAN.ino) with the esp32-libs_v3.0.1 library.
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

nagup, 2024-07-30:
@Llgok

That worked at last.

So I deleted the libraries which I pasted into the arduino libraries folder, these were called freenove, modbus and esp32 arduino CAN.

Replaced them with the libraries in the new branch you showed above.

Then I restarted arduino and opened an example in the examples folder of the arduino-esp32-libs v3.0.1 archive file and it uploaded fine.

please note I did not uninstall the arduino and espressif esp32 boards.

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

Llgok, 2024-07-31:
@nagup
Yes, please use the latest Arduino lib library examples for compilation in the future.

tejaslithium, 2025-07-06:
Compilation Error - esp_intr.h no such file or directory same again now i am facing

Closed 2024-08-21.

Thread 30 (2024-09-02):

RS485 question (A02 Sensor)

p0l0us, 2024-09-02:
Hi,
I'm trying to read ultrasonic distance sensor A02 / RS485 modbus data via T-CAN485.
https://wiki.icbbuy.com/lib/exe/fetch.php?media=developmentboard:a02-output-interfaces.pdf

But I'm not able to receive any data and my code (see below) always ends by timeout. I will appreciate any suggestions or help.

At least I would like to know `RS485_EN_PIN` and `RS485_SE_PIN` pins are for and how should I use them for reading and writing RS485 data ?
And what what `PIN_5V_EN` (pin 16) is for ?

```
	pinMode(RS485_EN_PIN, OUTPUT);
	digitalWrite(RS485_EN_PIN, HIGH);

	pinMode(RS485_SE_PIN, OUTPUT);
	digitalWrite(RS485_SE_PIN, HIGH);

	pinMode(PIN_5V_EN, OUTPUT);
	digitalWrite(PIN_5V_EN, HIGH);
```

In my code:

```
HardwareSerial UltrasoundLiquidLevelSensor::rs485(2);

void UltrasoundLiquidLevelSensor::setup()
{
	Serial.println("[UltrasoundLiquidLevelSensor] Setup...");

	this->rs485.begin(9600, SERIAL_8N1, RS485_RX_PIN, RS485_TX_PIN);

	byte GET_ADDRESS[8] = {0xFF, 0x03, 0x02, 0x00, 0x00, 0x01, 0x90, 0x6C};
	sendData(GET_ADDRESS);
	receiveData();

	delay(100);
}

void UltrasoundLiquidLevelSensor::sendData(byte *data)
{
	time = millis();
	this->rs485.write(data, 8);
	this->rs485.flush();
	delay(10);
}

void UltrasoundLiquidLevelSensor::receiveData()
{
	Serial.println("[UltrasoundLiquidLevelSensor] Receiving data...");
	byte data[8] = {0x00, 0x00, 0x00, 0x00, 0x00, 0x00, 0x00, 0x00};
	while (this->rs485.available() == 0)
	{
		Serial.print(".");
		if (millis() - time > TIMEOUT_DELAY)
		{
			Serial.println("\n[UltrasoundLiquidLevelSensor] Request Timed Out...");
			break;
		}
		delay(50);
	}
	Serial.print("\n");
	if (this->rs485.available() > 0)
	{
		this->rs485.readBytes(data, 7);
		for (int i = 0; i < 7; i++)
		{
			Serial.print(data[i], HEX);
			Serial.print(" ");
		}
		Serial.println();
	}
}

void UltrasoundLiquidLevelSensor::loop()
{
	byte GET_DISTANCE[8] = {0x01, 0x03, 0x01, 0x00, 0x00, 0x01, 0x85, 0xF6};
	sendData(GET_DISTANCE);
	receiveData();
	delay(2000);
}
```

Llgok, 2024-09-03:
@p0l0us
In the **main** branch.
1.  **RS485\_EN\_PIN**: This is the pin controlling the RS485 callback function. By default, during initialization, it is set to output a high level to disable the callback function.
2.  **RS485\_SE\_PIN**: This is the pin controlling the enable pin of the RS485 chip. By default, during initialization, it is set to output a high level to start the chip normally.
3.  **PIN\_5V\_EN**: This is the enable switch pin for the ME2107 power chip. The total power for RS485 is connected to this chip. By default, during initialization, it is set to output a high level to turn on the power switch.

In the **arduino-esp32-libs\_v3.0.1** branch:
The correct macro definitions are provided in the [pin_config.h](https://github.com/Xinyuan-LilyGO/T-CAN485/blob/arduino-esp32-libs_v3.0.1/libraries/Mylibrary/pin_config.h) file. You can refer to this file for further details.

The **main** branch is considered outdated, and future updates will be carried out in the **arduino-esp32-libs\_v3.0.1** branch. Any errors in the previous branches can be referenced by looking at the examples in the latest branch when programming. For example, you can refer to the [RS485_WS2812B.ino](https://github.com/Xinyuan-LilyGO/T-CAN485/blob/arduino-esp32-libs_v3.0.1/examples/RS485_WS2812B/RS485_WS2812B.ino) for programming examples.

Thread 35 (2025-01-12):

12v power burnt the IC

juliancuni, 2025-01-12:
Is this board 12v capable?
It was just bad luck that my board happens to be faulty?

I did programmed it, tested in my desk, usb powered, receiving CAN messages, generatiing PWM to controll a tachometer.
When I connected to 12v it popped the chip in the picture.
What is this chip?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

andrewfraley, 2025-02-06:
FWIW I was powering mine with 12V no problem for 48h or so.  Did you reverse the polarity maybe?

juliancuni, 2025-02-06:
@andrewfraley I am confident about polarity. Maybe the problem was that I tried to run it in a automotive environment. The voltage readings were some 14v.
I don't know. Maybe it was bad luck. I'll try the other board and record the whole process.
Thank you for your feedback anyway, the lilygo guys didn't bother to respond.

juliancuni, 2025-02-06:
@andrewfraley I am confident about polarity. Maybe the problem was that I tried to run it in a automotive environment. The voltage readings were some 14v.
I don't know. Maybe it was bad luck. I'll try the other board and record the whole process.
Thank you for your feedback anyway.

andrewfraley, 2025-02-15:
Mine’s been running for a week now on 12V, but seeing this prompted me to add a 1A inline fuse on the input.

juliancuni, 2025-02-15:
> input

I don't see how a fuse helps with voltage?

andrewfraley, 2025-02-16:
Just in case this thing decides to give up the ghost, mines enclosed with some batteries so I cant risk any sort of fire.

Giddy-Up224, 2025-10-06:
> [@andrewfraley](https://github.com/andrewfraley) I am confident about polarity. Maybe the problem was that I tried to run it in a automotive environment. The voltage readings were some 14v. I don't know. Maybe it was bad luck. I'll try the other board and record the whole process. Thank you for your feedback anyway.

I bet that's the issue. 12V in electronics are not always the nominal 12V of automotive circuits.

lewisxhe, 2025-10-07:
We have confirmed with the factory that U6 uses TMI3253, which supports up to 18V input, so 12V is not enough to break down the chip.

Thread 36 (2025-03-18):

Deye 50k BMS connection

Gubysh, 2025-03-18:
Hello
I need to set BMS ommunication LILYGO TTGO T-Can 485 ESP32 CAN RS-485 to deye inverter

I dont understand how to connect it

Gubysh, 2025-03-18:
Could i connect it to inverter using RS485 port on inverter board?

lewisxhe, 2025-03-24:
This board has RS485 and CAN interfaces. You need to find RS485_A and RS485_B of your device and connect these two interfaces to A+ B+ of this board. You also need to compile the code according to the protocol of your device before you can use it.

The connection diagram is probably like this

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

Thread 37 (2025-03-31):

RS485 and esphome

sobiso, 2025-03-31:
Hi,

I have strange issue, when I connect only my slave device to the bus it doesn't work. But when I also connect to the bus my computer via usb-rs485 the communication between the board and slave works and on computer I can see this communication (request and response)

My esphome configuration
```output:
  - platform: gpio
    id: ENABLE_PIN # Enable the chip
    pin:
      number: GPIO19
      inverted: true
  - platform: gpio
    id: SE_PIN # Enable autodirection
    pin:
      number: GPIO17
      inverted: true
  - platform: gpio
    id: ENABLE_5V_PIN # Enable 5V pin for RS485 chip
    pin:
      number: GPIO16
      inverted: true

uart:
  id: mod_uart
  rx_pin: GPIO21
  tx_pin: GPIO22
  baud_rate: 9600
  debug:
    direction: BOTH
    dummy_receiver: false
    after:
      delimiter: "\n"
    sequence:
      - lambda: UARTDebug::log_string(direction, bytes);

modbus:
  id: modbus1
  uart_id: mod_uart

modbus_controller:
- id: modbus_device
  address: 0x1   ## address of the Modbus slave device on the bus
  modbus_id: modbus1
  setup_priority: -10
  update_interval: 10s

sensor:
- platform: modbus_controller
  modbus_controller_id: modbus_device
  register_type: holding
  name: "ASP-215 Temerature"
  address: 0x0600    ## address of the register inside the Modbus slave device
  unit_of_measurement: "°C"
  value_type: S_WORD```

lewisxhe, 2025-04-01:
```c
switch:
  - platform: gpio
    id: ENABLE_PIN
    pin:
      number: GPIO19
      inverted: true
    restore_mode: ALWAYS_ON

  - platform: gpio
    id: SE_PIN
    pin:
      number: GPIO17
      inverted: true
    restore_mode: ALWAYS_ON
  - platform: gpio
    id: ENABLE_5V_PIN
    pin:
      number: GPIO16
      inverted: true
    restore_mode: ALWAYS_ON
```
Try adding Always open

sobiso, 2025-04-02:
I changed resistors 4k7, pull up and pull down, and it works.

lewisxhe, 2025-04-07:
Which resistor did you change? Can you share?

sobiso, 2025-04-07:
Next to MAX13486, R3 and R8. Both to 330 Ohm

Closed 2025-04-02.

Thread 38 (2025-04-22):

CAN BUS Interrupt Pin

cosmin91, 2025-04-22:
Hi, I've tried a lot of code versions, but seems like I'm not able to wake up the esp32 when I receive a new CAN message. It's probably a hardware limitation, but just want to double check if there is something that will trigger the wakeup pin on esp32 when there is can bus activity.
Thanks,
Cosmin

lewisxhe, 2025-04-23:
Do you mean esp32 in sleep mode? CAN interrupt??

cosmin91, 2025-04-23:
@lewisxhe yes, exactly.

lewisxhe, 2025-04-23:
ESP does not have a separate wake-up function for CAN

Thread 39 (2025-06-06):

RS485 and virtual serial port

CreasolTech, 2025-06-06:
Hi,
is it possible to use the module as a virtual serial port, like you can do with with
* **socat** on the main controller and
* **ser2net** in the slave module connected to a RS485 bus?

It will be useful to connect RS485 devices that do not use the standard Modbus protocol.
Thanks.
Paolo

lewisxhe, 2025-06-09:
https://github.com/espressif/arduino-esp32/blob/master/libraries/WiFi/examples/WiFiClientBasic/WiFiClientBasic.ino

https://github.com/Xinyuan-LilyGO/T-CAN485/blob/main/example/Arduino/RS485/RS485.ino

You just need to send the message received by rs485 through TCP. You can refer to these two examples.

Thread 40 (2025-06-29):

I2C pins

githubcdr, 2025-06-29:
Hi,

What PINS can I use for I2C? I tried GPIO32 and GPIO33 for SDA and SCL but that does not work.

Regards,

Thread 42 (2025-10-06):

library named incorrectly when used in PlatformIO as URL in platformio.ini `lib_deps`

Giddy-Up224, 2025-10-06:
I added this to my platformio.ini file like:

```
lib_deps =
    https://github.com/Xinyuan-LilyGO/T-CAN485
```

It downloads fine but it names the folder in the `libdeps` folder `FastLED`, presumably because there is no library.json file in the repo root and `FastLED-3.7.0` is in the `lib` folder. Could you add a proper `library.json` so that it names the folder correctly when using it in PlatformIO?

<br></br>
**Example library.json**
```json
{
  "name": "T-CAN485",
  "version": "1.0.0",
  "description": "Library for LilyGO T-CAN485 board",
  "keywords": ["can", "rs485", "lilygo", "esp32"],
  "repository": {
    "type": "git",
    "url": "https://github.com/Xinyuan-LilyGO/T-CAN485"
  },
  "frameworks": ["arduino"],
  "platforms": ["espressif32"],
  "authors": [
    {
      "name": "Xinyuan-LilyGO",
      "url": "https://github.com/Xinyuan-LilyGO"
    }
  ],
  "license": "MIT"
}
```

lewisxhe, 2025-10-07:
T-CAN485 is not a platformIO library. I don't understand your purpose of doing this.

Giddy-Up224, 2025-10-07:
> T-CAN485 is not a library. I don't understand your purpose of doing this.

I read the README more thoroughly and see that you're not using this as a library but more as documentation and examples.

Closed 2025-10-07.

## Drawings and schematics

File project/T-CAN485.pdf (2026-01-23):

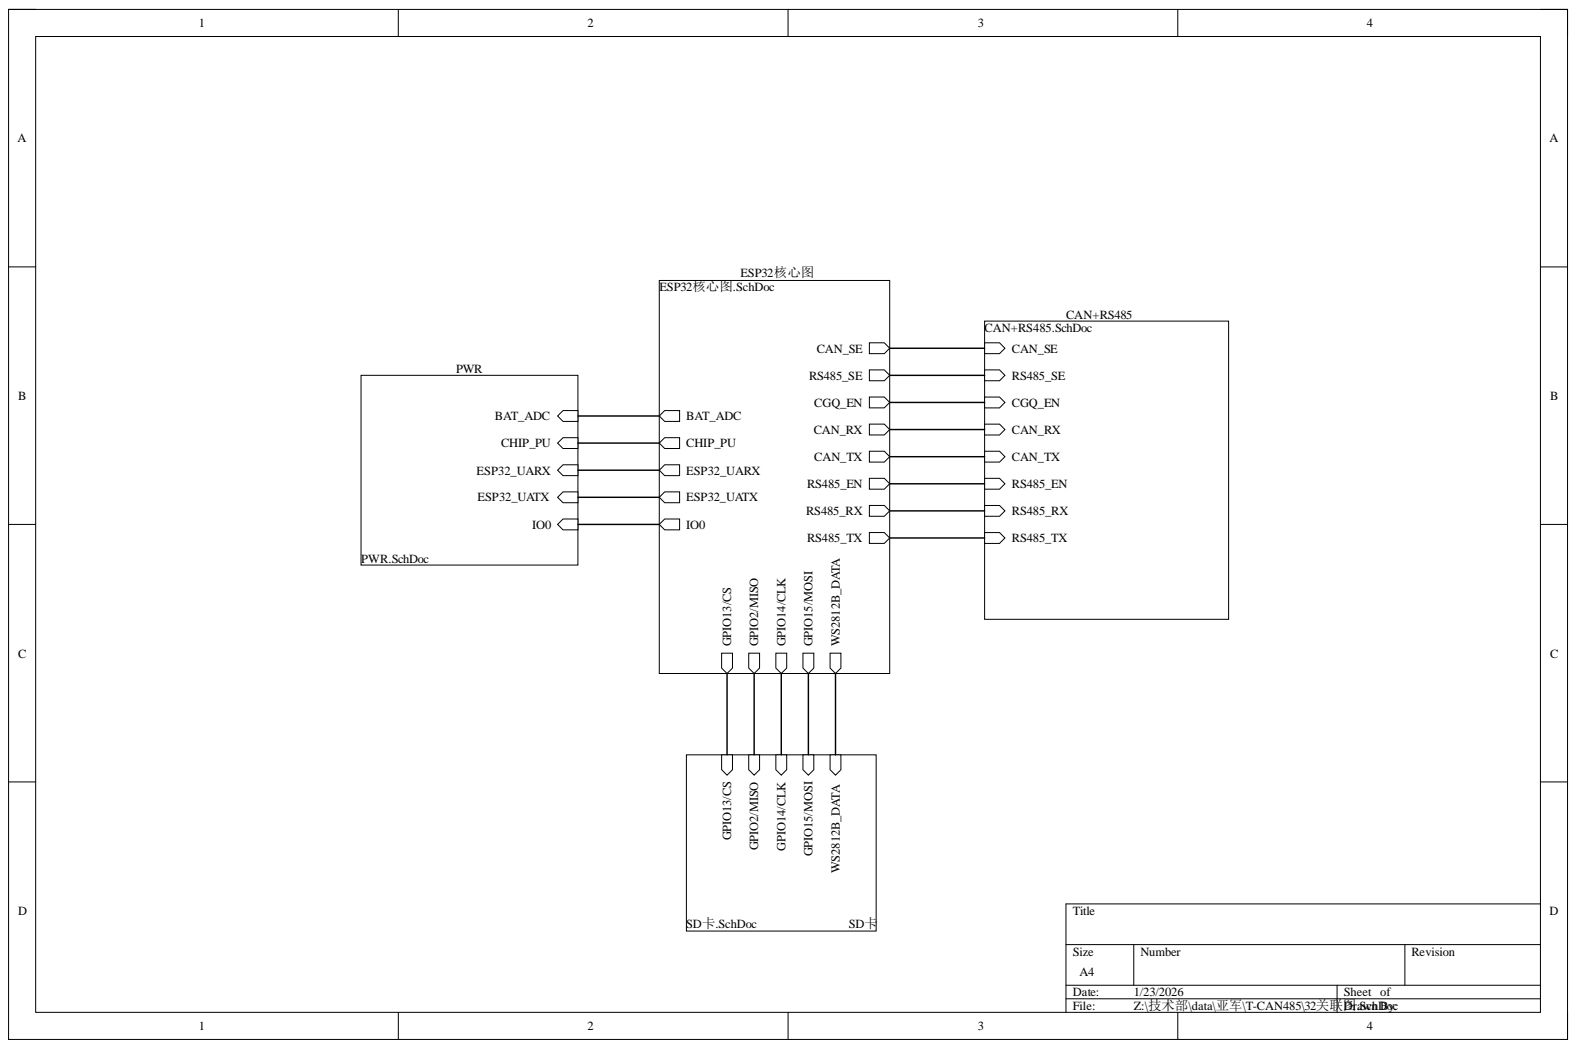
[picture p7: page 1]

Size A4 | Number | Revision

Date: 1/23/2026 | Sheet of
File: Z:\技术部\data\亚军\T-CAN485\32关联图Dr.aSwn chDBoyc:

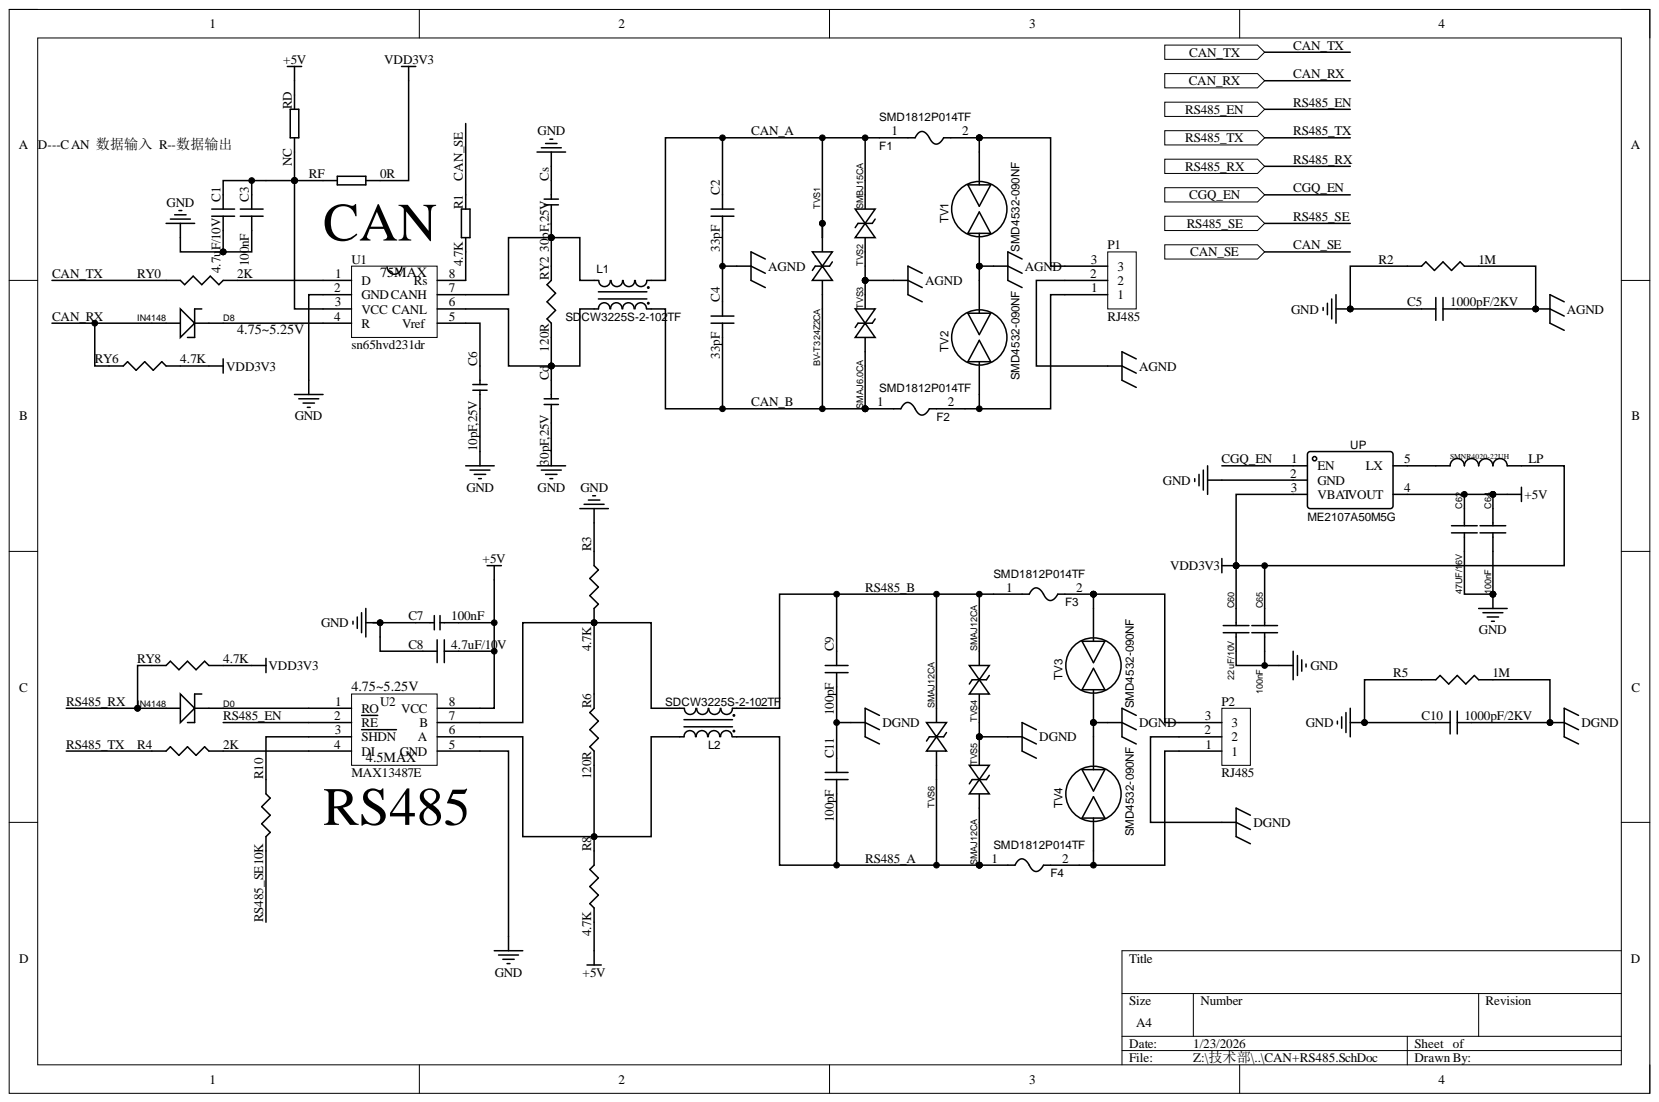
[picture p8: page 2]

4 | 5 | S D C

Siz e A4 | Numb e r | R evisio n

Da te : 1/23/202 6 | She et of
File : Z:\技术部\. . \ CAN+ R S485. S c hD o c | Dr awn B y :

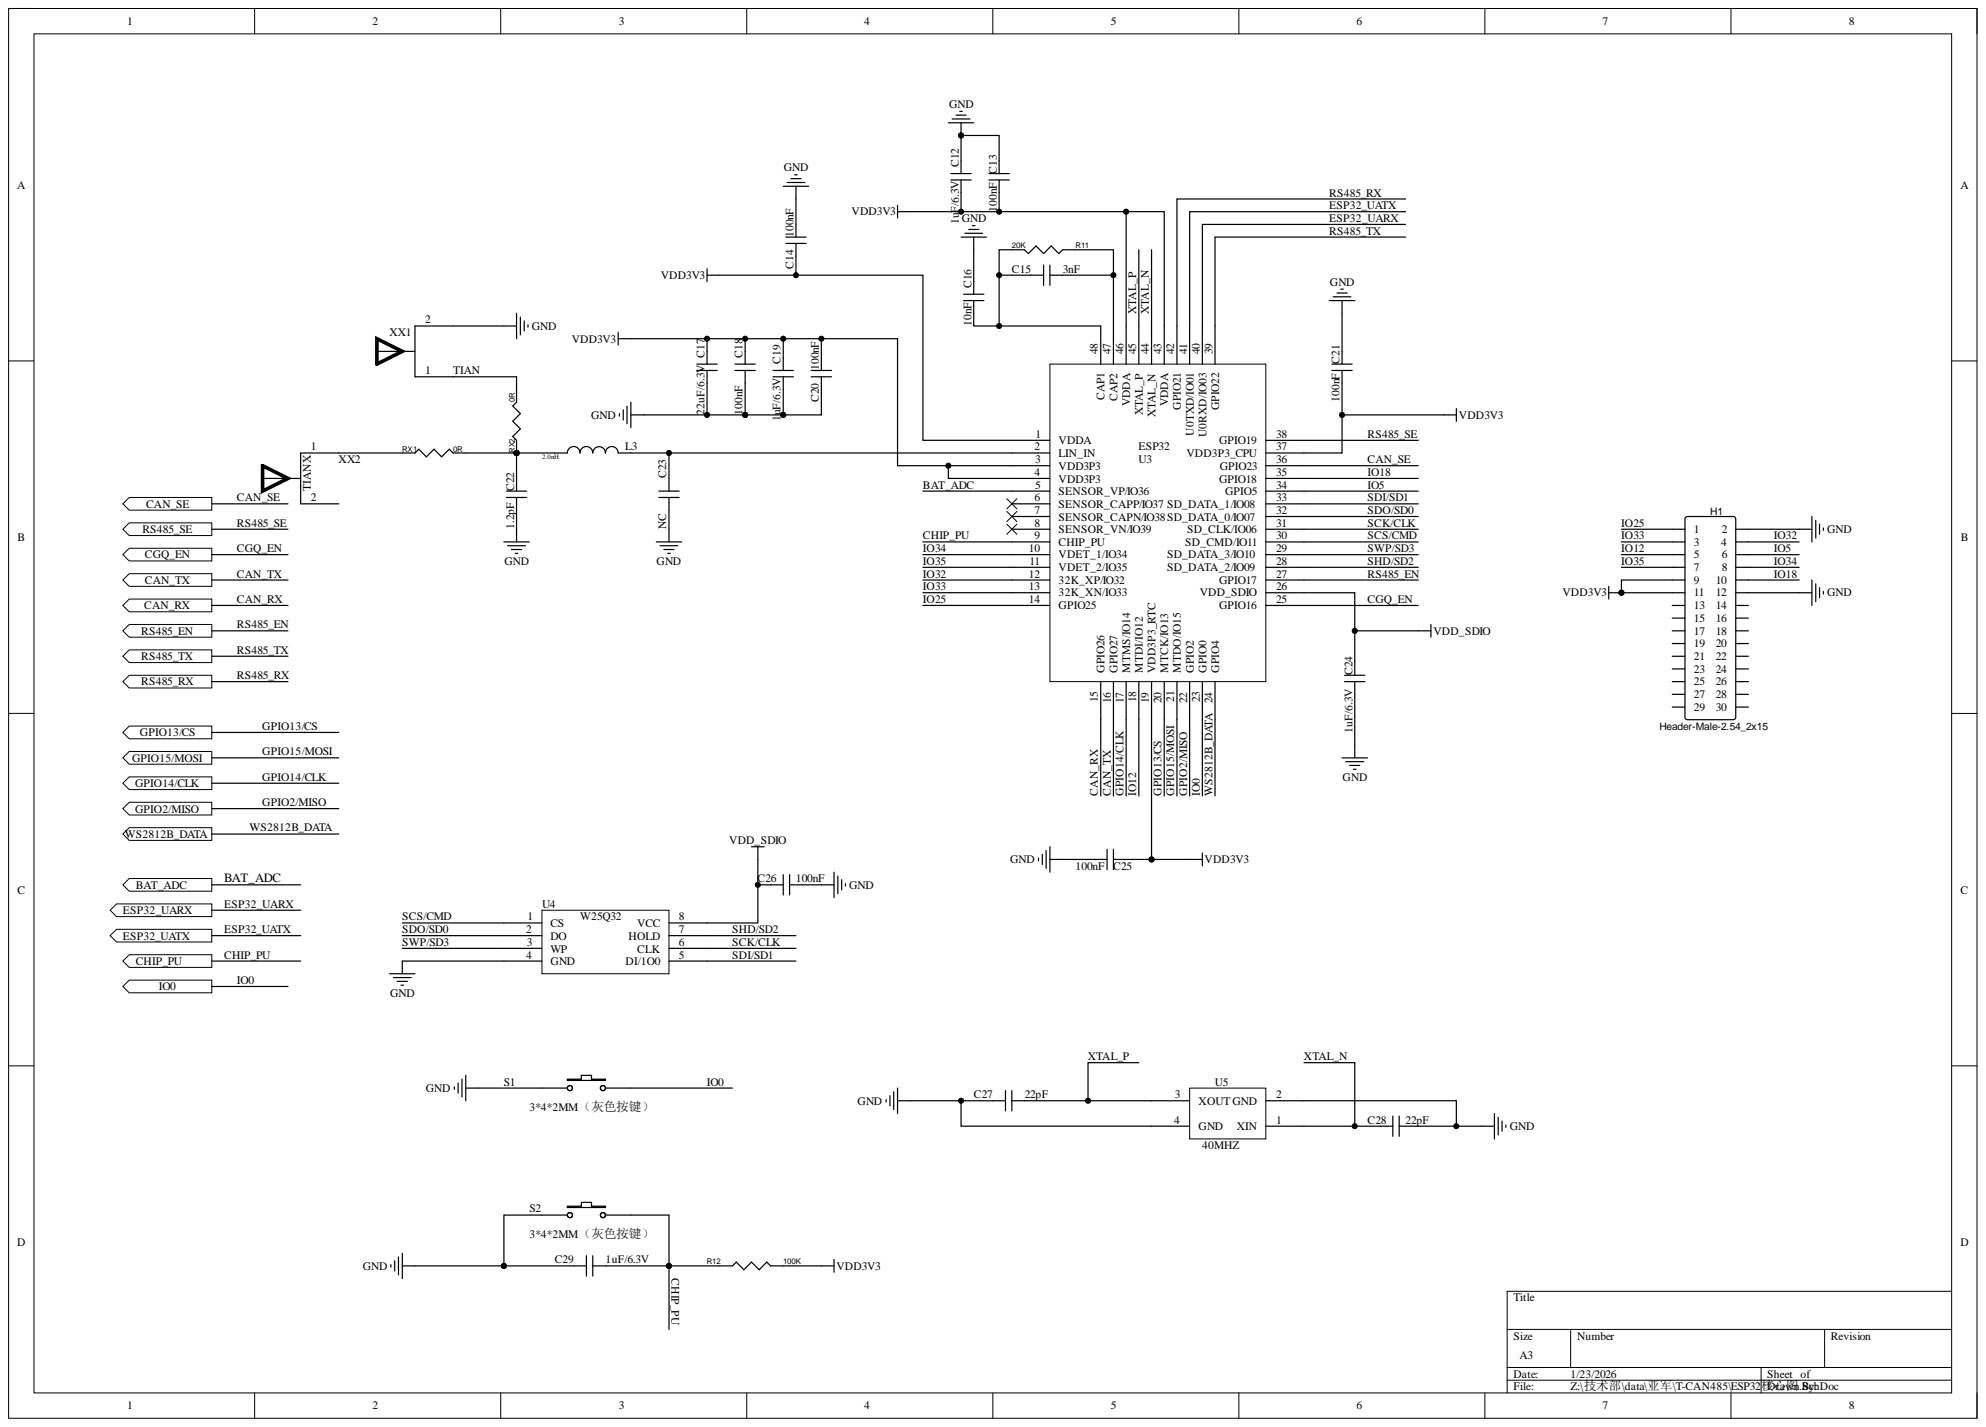
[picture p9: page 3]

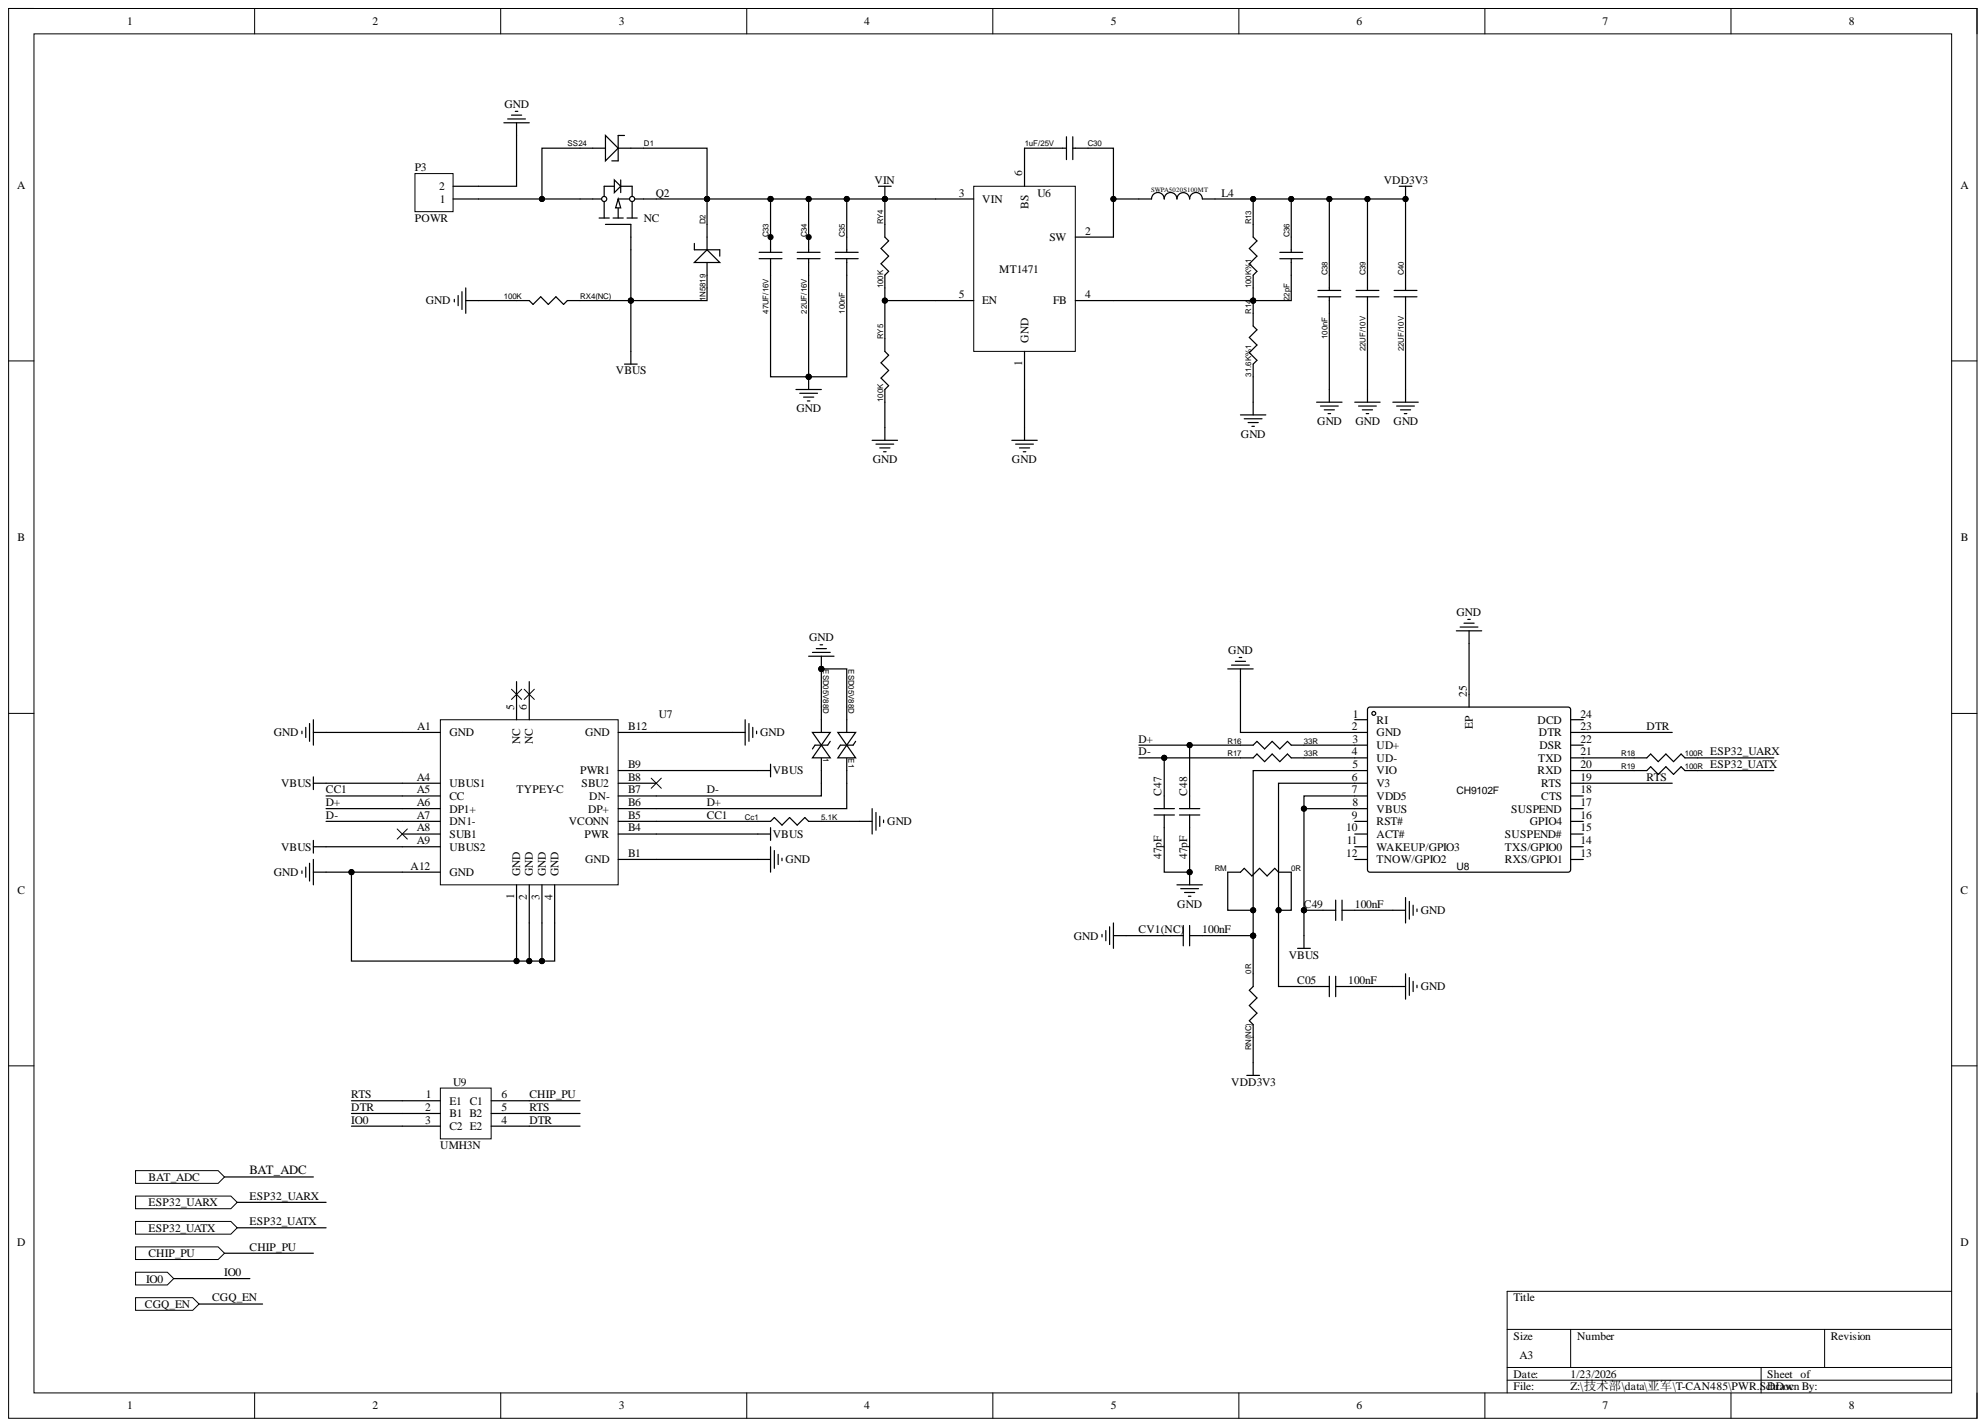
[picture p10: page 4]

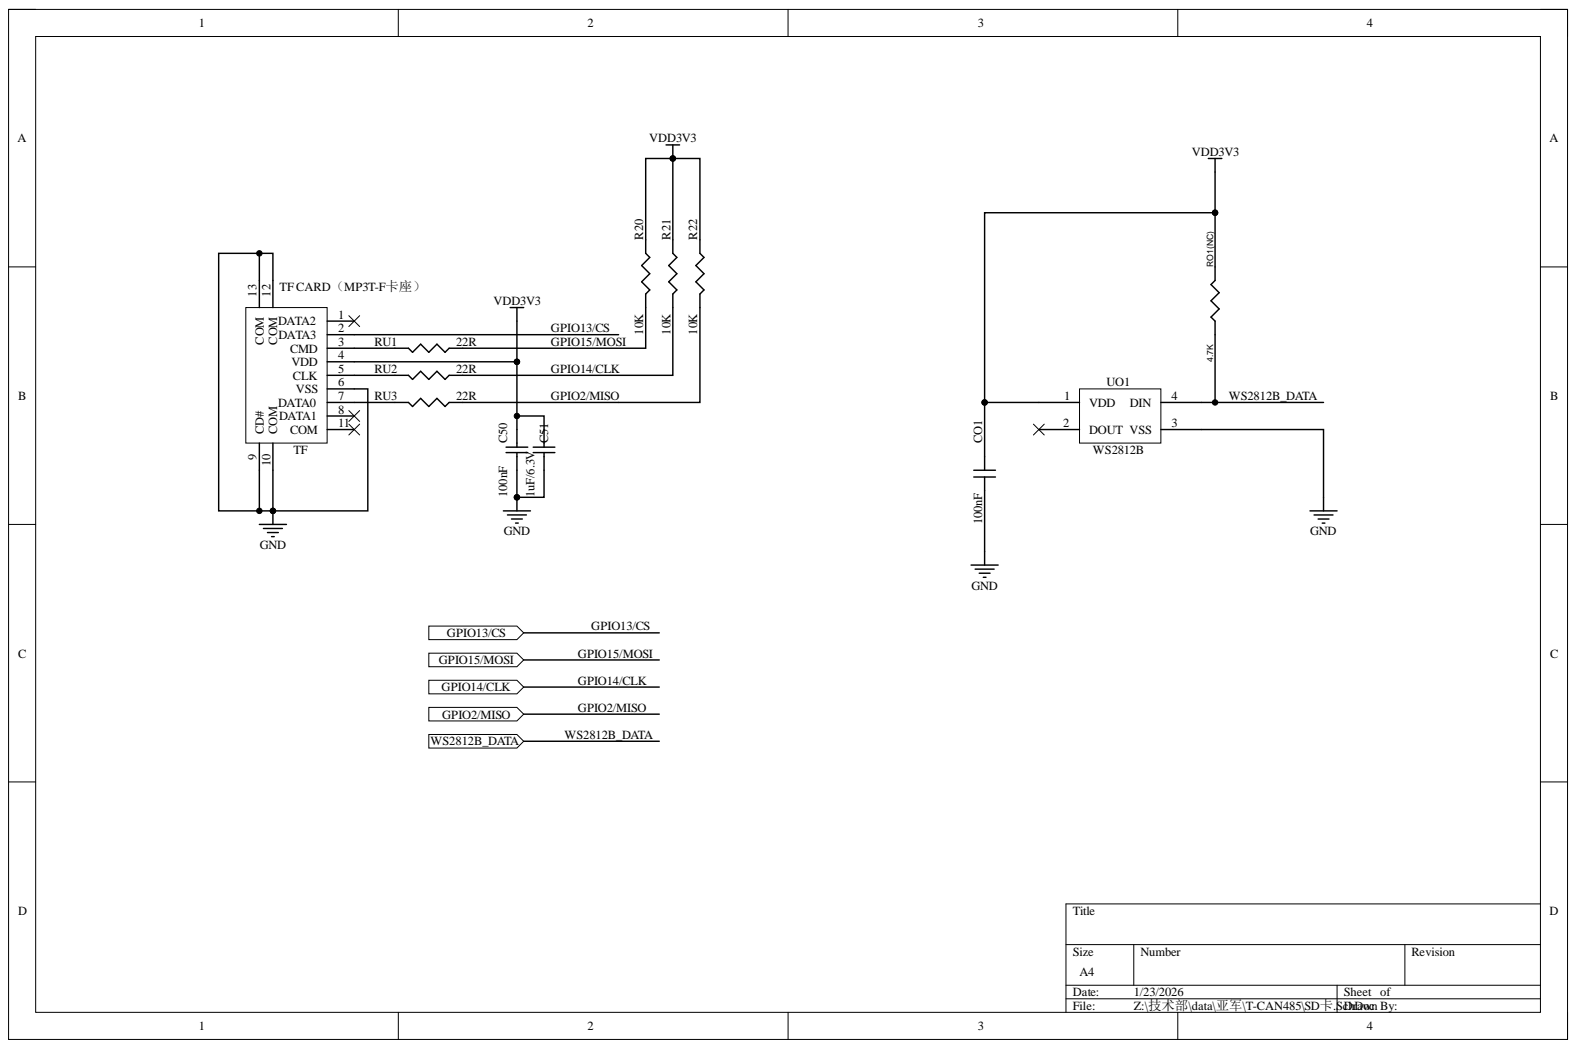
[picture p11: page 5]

Size A4 | Number | Revision

Date: 1/23/2026 | Sheet of
File: Z:\技术部\data\亚军\T-CAN485\SD卡.ScDrhDawn oc By:

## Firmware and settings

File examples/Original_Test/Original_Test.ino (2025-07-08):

/*
 * @Description: 
        Factory testing
        Connect both RS485 and CAN buses simultaneously, wait for all initializations to complete, 
    then press the BOOT button on one of the boards to activate the test program. You can observe
    the communication between the two devices in the computer window. If there is an error in 
    the RS485 communication, all communication will stop and a red light will turn on.
 * @version: V1.0.0
 * @Author: LILYGO_L
 * @Date: 2023-08-16 15:19:01
 * @LastEditors: LILYGO_L
 * @LastEditTime: 2024-06-24 10:34:14
 * @License: GPL 3.0
 */
#include <Arduino.h>
#include "WiFi.h"
#include <HTTPClient.h>
#include "pin_config.h"
#include <HardwareSerial.h>
#include "FastLED.h"
#include <Wire.h>
#include <SPI.h>
#include <SD.h>
#include "driver/twai.h"

#define WIFI_SSID "xinyuandianzi"
#define WIFI_PASSWORD "AA15994823428"
// #define WIFI_SSID "LilyGo-AABB"
// #define WIFI_PASSWORD "xinyuandianzi"

#define WIFI_CONNECT_WAIT_MAX (5000)

#define NUM_LEDS 1
#define DATA_PIN WS2812B_DATA

// Intervall:
#define TRANSMIT_RATE_MS 1000
#define POLLING_RATE_MS 1000

bool Wifi_Connection_Failure_Flag = false;

static size_t CycleTime = 0;
static uint8_t Uart_Buf[105] = {0};

static uint32_t Uart_Count = 0;

static bool SelfLocking_Flag = false;

static uint8_t Uart_Data[] = {

    0x0A, // 设备标头识别

    // 动态数据计数
    0B00000000, // 数据高2位
    0B00000000, // 数据高1位
    0B00000000, // 数据低2位
    0B00000000, // 数据低1位

    // 100个数据包
    0xAA,
    0xAA,
    0xAA,
    0xAA,
    0xAA,
    0xAA,
    0xAA,
    0xAA,
    0xAA,
    0xAA,
    0xAA,
    0xAA,
    0xAA,
    0xAA,
    0xAA,
    0xAA,
    0xAA,
    0xAA,
    0xAA,
    0xAA,
    0xAA,
    0xAA,
    0xAA,
    0xAA,
    0xAA,
    0xAA,
    0xAA,
    0xAA,
    0xAA,
    0xAA,
    0xAA,
    0xAA,
    0xAA,
    0xAA,
    0xAA,
    0xAA,
    0xAA,
    0xAA,
    0xAA,
    0xAA,
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
};

const char *fileDownloadUrl = "http://music.163.com/song/media/outer/url?id=26122999.mp3";

CRGB leds[NUM_LEDS];

void Wifi_STA_Test(void)
{
    String text;
    int wifi_num = 0;

    Serial.println("\nScanning wifi");

    WiFi.mode(WIFI_STA);
    WiFi.disconnect();
    delay(100);

    wifi_num = WiFi.scanNetworks();
    if (wifi_num == 0)
    {
        text = "\nWiFi scan complete !\nNo wifi discovered.\n";
    }
    else
    {
        text = "\nWiFi scan complete !\n";
        text += wifi_num;
        text += " wifi discovered.\n\n";

        for (int i = 0; i < wifi_num; i++)
        {
            text += (i + 1);
            text += ": ";
            text += WiFi.SSID(i);
            text += " (";
            text += WiFi.RSSI(i);
            text += ")";
            text += (WiFi.encryptionType(i) == WIFI_AUTH_OPEN) ? " \n" : "*\n";
            delay(10);
        }
    }

    Serial.println(text);

    delay(3000);
    text.clear();

    text = "Connecting to ";
    Serial.print("Connecting to ");
    text += WIFI_SSID;
    text += "\n";

    Serial.print(WIFI_SSID);

    WiFi.begin(WIFI_SSID, WIFI_PASSWORD);

    uint32_t last_tick = millis();

    while (WiFi.status() != WL_CONNECTED)
    {
        Serial.print(".");
        text += ".";
        delay(100);

        if (millis() - last_tick > WIFI_CONNECT_WAIT_MAX)
        {
            Wifi_Connection_Failure_Flag = true;
            break;
        }
    }

    if (!Wifi_Connection_Failure_Flag)
    {
        text += "\nThe connection was successful ! \nTakes ";
        Serial.print("\nThe connection was successful ! \nTakes ");
        text += millis() - last_tick;
        Serial.print(millis() - last_tick);
        text += " ms\n";
        Serial.println(" ms\n");
    }
    else
    {
        Serial.printf("\nWifi test error!\n");
    }
}

bool Uart_Check_Dynamic_Data(uint8_t *uart_data, uint32_t check_data)
{
    uint32_t temp;

    temp = (uint32_t)uart_data[1] << 24 | (uint32_t)uart_data[2] << 16 |
           (uint32_t)uart_data[3] << 8 | (uint32_t)uart_data[4];

    if (temp == check_data)
    {
        return true;
    }

    return false;
}

bool Uart_Check_Static_Data(uint8_t *uart_data)
{
    if (memcmp(&uart_data[5], &Uart_Data[5], 100) == 0)
    {
        return true;
    }
    return false;
}

void SD_Test()
{
    uint8_t cardType = 0;
    uint64_t cardSize = 0;
    uint8_t numSectors = 0;

    if (!SD.begin(SD_CS, SPI, 40000000)) // SD boots
    {
        SelfLocking_Flag = false;

        Serial.println("Detecting SD card");

        Serial.println("SD card initialization failed !");
        delay(100);

        Serial.println(".");
        delay(100);

        Serial.println(".");
        delay(100);

        Serial.println(".");
        delay(100);

        Serial.println(".");
        delay(100);

        Serial.println(".");
        delay(100);

        Serial.println(".");
        delay(100);
    }
    else
    {
        delay(50); // Wait for the SD card

        if (SelfLocking_Flag == false)
        {
            SelfLocking_Flag = true;
            delay(50);
        }

        Serial.println("SD card initialization successful !");
        delay(100);

        cardType = SD.cardType();
        cardSize = SD.cardSize() / (1024 * 1024);
        numSectors = SD.numSectors();
        switch (cardType)
        {
        case CARD_NONE:
            Serial.println("No SD card attached");
            delay(100);

            break;
        case CARD_MMC:
            Serial.print("SD Card Type: ");
            Serial.println("MMC");
            Serial.printf("SD Card Size: %lluMB\n", cardSize);
            delay(100);

            break;
        case CARD_SD:
            Serial.print("SD Card Type: ");
            Serial.println("SDSC");
            Serial.printf("SD Card Size: %lluMB\n", cardSize);
            delay(100);

            break;
        case CARD_SDHC:
            Serial.print("SD Card Type: ");
            Serial.println("SDHC");
            Serial.printf("SD Card Size: %lluMB\n", cardSize);
            delay(100);

            break;
        default:
            Serial.println("UNKNOWN");
            delay(100);

            break;
        }
    }
    SD.end();
}

void CAN_Drive_Initialization()
{
    // Initialize configuration structures using macro initializers
    twai_general_config_t g_config = TWAI_GENERAL_CONFIG_DEFAULT((gpio_num_t)CAN_TX, (gpio_num_t)CAN_RX, TWAI_MODE_NORMAL);
    twai_timing_config_t t_config = TWAI_TIMING_CONFIG_500KBITS();
    twai_filter_config_t f_config = TWAI_FILTER_CONFIG_ACCEPT_ALL();

    // Install TWAI driver
    if (twai_driver_install(&g_config, &t_config, &f_config) == ESP_OK)
    {
        Serial.println("Driver installed");
    }
    else
    {
        Serial.println("Failed to install driver");
    }

    // Start TWAI driver
    if (twai_start() == ESP_OK)
    {
        Serial.println("Driver started");
    }
    else
    {
        Serial.println("Failed to start driver");
    }

    // 配置
    uint32_t alerts_to_enable = TWAI_ALERT_TX_IDLE | TWAI_ALERT_TX_SUCCESS |
                                TWAI_ALERT_TX_FAILED | TWAI_ALERT_ERR_PASS |
                                TWAI_ALERT_BUS_ERROR | TWAI_ALERT_RX_DATA |
                                TWAI_ALERT_RX_QUEUE_FULL;

    if (twai_reconfigure_alerts(alerts_to_enable, NULL) == ESP_OK)
    {
        Serial.println("CAN Alerts reconfigured");
    }
    else
    {
        Serial.println("Failed to reconfigure alerts");
    }
}

void Twai_Send_Message()
{
    // Configure message to transmit
    twai_message_t message;
    message.extd = 0; // 标准帧
    message.rtr = 0;  // 非远程帧
    message.identifier = 0xF1;
    // message.data_length_code = 1;
    // message.data[0] = CAN_Count++;
    message.data_length_code = 8;
    message.data[0] = 1;
    message.data[1] = 2;
    message.data[2] = 3;
    message.data[3] = 4;
    message.data[4] = 5;
    message.data[5] = 6;
    message.data[6] = 7;
    message.data[7] = 8;

    // Queue message for transmission
    if (twai_transmit(&message, pdMS_TO_TICKS(1000)) == ESP_OK)
    {
        printf("Message queued for transmission\n");
    }
    else
    {
        printf("Failed to queue message for transmission\n");
    }
}

void Twai_Receive_Message(twai_message_t &message)
{
    // Process received message
    if (message.extd)
    {
        Serial.println("Message is in Extended Format");
    }
    else
    {
        Serial.println("Message is in Standard Format");
    }
    Serial.printf("ID: 0x%X\n", message.identifier);
    if (!(message.rtr))
    {
        for (int i = 0; i < message.data_length_code; i++)
        {
            Serial.printf("Data [%d] = %d\n", i, message.data[i]);
        }
        Serial.println("");
    }
}

void setup()
{
    Serial.begin(115200);
    Serial.println("Ciallo");

    pinMode(0, INPUT_PULLUP);

    pinMode(ME2107_EN, OUTPUT);
    digitalWrite(ME2107_EN, HIGH);

    pinMode(RS485_CALLBACK, OUTPUT);
    pinMode(RS485_EN, OUTPUT);
    digitalWrite(RS485_EN, HIGH);
    digitalWrite(RS485_CALLBACK, HIGH); // 禁用输出接收到的信号 禁用回调

    // High speed mode
    pinMode(CAN_SPEED_MODE, OUTPUT);
    digitalWrite(CAN_SPEED_MODE, LOW);

    CAN_Drive_Initialization();

    // 初始化串口，并重新定义引脚
    // 参数包括串行通信的波特率、串行模式、使用的 RX 引脚和 TX 引脚。
    Serial1.begin(921600, SERIAL_8N1, RS485_RX, RS485_TX);

    FastLED.addLeds<WS2812B, DATA_PIN, GRB>(leds, NUM_LEDS); // GRB ordering is typical
    FastLED.setBrightness(20);

    leds[0] = CRGB::Red;
    FastLED.show();
    delay(1000);

    leds[0] = CRGB::Green;
    FastLED.show();
    delay(1000);

    leds[0] = CRGB::Blue;
    FastLED.show();
    delay(1000);

    leds[0] = CRGB::White;
    FastLED.show();
    delay(1000);

    Wifi_STA_Test();
    delay(2000);

    if (!Wifi_Connection_Failure_Flag)
    {
        // 初始化HTTP客户端
        HTTPClient http;
        http.begin(fileDownloadUrl);
        // 获取重定向的URL
        const char *headerKeys[] = {"Location"};
        http.collectHeaders(headerKeys, 1);

        // 记录下载开始时间
        size_t startTime = millis();
        // 无用时间
        size_t uselessTime = 0;

        // 发起GET请求
        int httpCode = http.GET();

        while (httpCode == HTTP_CODE_MOVED_PERMANENTLY || httpCode == HTTP_CODE_FOUND)
        {
            String newUrl = http.header("Location");
            Serial.printf("Redirecting to: %s\n", newUrl.c_str());
            http.end(); // 关闭旧的HTTP连接

            // 使用新的URL重新发起GET请求
            http.begin(newUrl);
            httpCode = http.GET();
        }

        if (httpCode == HTTP_CODE_OK)
        {
            // 获取文件大小
            size_t fileSize = http.getSize();
            Serial.printf("Starting file download...\n");
            Serial.printf("file size: %f Mb\n", fileSize / 1024.0 / 1024.0);

            // 读取HTTP响应
            WiFiClient *stream = http.getStreamPtr();

            size_t temp_count_s = 0;
            size_t temp_fileSize = fileSize;
            uint8_t *buf_1 = (uint8_t *)heap_caps_malloc(100 * 1024, MALLOC_CAP_INTERNAL | MALLOC_CAP_8BIT);
            // uint8_t buf_1[4096] = {0};
            CycleTime = millis() + 1000; // 开始计时
            bool temp_count_flag = true;
            while (http.connected() && (fileSize > 0 || fileSize == -1))
            {
                // 获取可用数据的大小
                size_t availableSize = stream->available();
                if (availableSize)
                {
                    temp_fileSize -= stream->read(buf_1, min(availableSize, (size_t)(100 * 1024)));

                    if (millis() > CycleTime)
                    {
                        size_t temp_time_1 = millis();
                        temp_count_s++;
                        Serial.printf("Download speed: %f Kb/s\n", ((fileSize - temp_fileSize) / 1024.0) / temp_count_s);
                        Serial.printf("Remaining file size: %f Mb\n\n", temp_fileSize / 1024.0 / 1024.0);

                        CycleTime = millis() + 1000;
                        size_t temp_time_2 = millis();

                        uselessTime = uselessTime + (temp_time_2 - temp_time_1);
                    }
                }
                // delay(1);

                if (temp_fileSize == 0)
                {
                    break;
                }

                if (temp_count_s > 30)
                {
                    temp_count_flag = false;
                    break;
                }
            }

            // 关闭HTTP客户端
            http.end();

            // 记录下载结束时间并计算总花费时间
            size_t endTime = millis();

            if (temp_count_flag == true)
            {
                Serial.printf("Download completed!\n");
                Serial.printf("Total download time: %f s\n", (endTime - startTime - uselessTime) / 1000.0);
                Serial.printf("Average download speed: %f Kb/s\n", (fileSize / 1024.0) / ((endTime - startTime - uselessTime) / 1000.0));
            }
            else
            {
                Serial.printf("Download incomplete!\n");
                Serial.printf("Download time: %f s\n", (endTime - startTime - uselessTime) / 1000.0);
                Serial.printf("Average download speed: %f Kb/s\n", ((fileSize - temp_fileSize) / 1024.0) / ((endTime - startTime - uselessTime) / 1000.0));
            }
        }
        else
        {
            Serial.printf("Failed to download\n");
            Serial.printf("Error httpCode: %d \n", httpCode);
        }
    }
    else
    {
        Serial.print("Not connected to the network");
    }
    delay(1000);

    leds[0] = CRGB::Purple;
    FastLED.show();
    delay(1000);

    SPI.begin(SD_SCLK, SD_MISO, SD_MOSI, SD_CS); // SPI boots
    SD_Test();

    leds[0] = CRGB::Black;
    FastLED.show();

    while (Serial1.available() > 0) // 清空缓存
    {
        Serial1.read();
    }
}

void loop()
{
    if (digitalRead(0) == 0)
    {
        delay(300);

        leds[0] = CRGB::Blue;
        FastLED.show();
        delay(1000);
        Serial1.write(Uart_Data, 105);

        Uart_Count++;
        leds[0] = CRGB::Black;
        FastLED.show();

        Twai_Send_Message();
        Serial.println("CAN send done");
    }

    while (Serial1.available() > 0)
    {
        delay(1000); // 接收等待
        Serial1.read(Uart_Buf, sizeof(Uart_Buf));

        if (Uart_Buf[0] == 0x0A)
        {
            if (Uart_Check_Dynamic_Data(Uart_Buf, Uart_Count) == false) // 动态数据校验
            {
                leds[0] = CRGB::Red;
                FastLED.show();
                while (1)
                {
                    Serial.printf("Check Dynamic Data Failed\n");
                    Serial.printf("Check Data: %d\n", Uart_Count);
                    Serial.printf("Received Data: %d\n", (uint32_t)Uart_Buf[1] << 24 | (uint32_t)Uart_Buf[2] << 16 |
                                                              (uint32_t)Uart_Buf[3] << 8 | (uint32_t)Uart_Buf[4]);
                    Serial.printf("Received Buf[1]: %#X\n", Uart_Buf[1]);
                    Serial.printf("Received Buf[2]: %#X\n", Uart_Buf[2]);
                    Serial.printf("Received Buf[3]: %#X\n", Uart_Buf[3]);
                    Serial.printf("Received Buf[4]: %#X\n", Uart_Buf[4]);
                    delay(1000);
                }
            }
            else if (Uart_Check_Static_Data(Uart_Buf) == false) // 静态数据校验
            {
                leds[0] = CRGB::Pink;
                FastLED.show();
                Serial.printf("Check Static Data Failed\n");
                for (int i = 0; i < 100; i++)
                {
                    Serial.printf("Received Buf[%d]: %#X\n", i + 5, Uart_Buf[i + 5]);
                }
                delay(1000);
            }
            else
            {
                leds[0] = CRGB::Green;
                FastLED.show();
                delay(500);

                Serial.printf("Check Data Successful\n");
                Serial.printf("Check Data: %d\n", Uart_Count);
                Serial.printf("Received Data: %d\n", (uint32_t)Uart_Buf[1] << 24 | (uint32_t)Uart_Buf[2] << 16 |
                                                          (uint32_t)Uart_Buf[3] << 8 | (uint32_t)Uart_Buf[4]);
                Serial.printf("Received Buf[1]: %#X\n", Uart_Buf[1]);
                Serial.printf("Received Buf[2]: %#X\n", Uart_Buf[2]);
                Serial.printf("Received Buf[3]: %#X\n", Uart_Buf[3]);
                Serial.printf("Received Buf[4]: %#X\n", Uart_Buf[4]);

                Serial.printf("Received Buf[105]: %#X\n", Uart_Buf[104]);

                Uart_Count++;

                Uart_Data[1] = Uart_Count >> 24;
                Uart_Data[2] = Uart_Count >> 16;
                Uart_Data[3] = Uart_Count >> 8;
                Uart_Data[4] = Uart_Count;

                delay(1000);
                Serial1.write(Uart_Data, 105);

                Uart_Count++;

                leds[0] = CRGB::Black;
                FastLED.show();
            }
        }
        else
        {
            leds[0] = CRGB::Orange;
            FastLED.show();
            delay(500);
            Serial.printf("Check Header Failed\n");
            Serial.printf("Received Header: %#X\n", Uart_Buf[0]);
            Serial.printf("Received Data: %d\n", (uint32_t)Uart_Buf[1] << 24 | (uint32_t)Uart_Buf[2] << 16 |
                                                      (uint32_t)Uart_Buf[3] << 8 | (uint32_t)Uart_Buf[4]);
            Serial.printf("Received Buf[1]: %#X\n", Uart_Buf[1]);
            Serial.printf("Received Buf[2]: %#X\n", Uart_Buf[2]);
            Serial.printf("Received Buf[3]: %#X\n", Uart_Buf[3]);
            Serial.printf("Received Buf[4]: %#X\n", Uart_Buf[4]);
            leds[0] = CRGB::Black;
            FastLED.show();
        }

        Twai_Send_Message();
        Serial.println("CAN send done");
    }

    // 通信报警检测
    uint32_t alerts_triggered;
    twai_read_alerts(&alerts_triggered, pdMS_TO_TICKS(POLLING_RATE_MS));
    // 总线状态信息
    twai_status_info_t twai_status_info;
    twai_get_status_info(&twai_status_info);

    switch (alerts_triggered)
    {
    case TWAI_ALERT_ERR_PASS:
        Serial.println("\nAlert: TWAI controller has become error passive.");
        delay(1000);
        break;
    case TWAI_ALERT_BUS_ERROR:
        Serial.println("\nAlert: A (Bit, Stuff, CRC, Form, ACK) error has occurred on the bus.");
        Serial.printf("Bus error count: %d\n", twai_status_info.bus_error_count);
        delay(1000);
        break;
    case TWAI_ALERT_TX_FAILED:
        Serial.println("\nAlert: The Transmission failed.");
        Serial.printf("TX buffered: %d\t", twai_status_info.msgs_to_tx);
        Serial.printf("TX error: %d\t", twai_status_info.tx_error_counter);
        Serial.printf("TX failed: %d\n", twai_status_info.tx_failed_count);
        delay(1000);
        break;
    case TWAI_ALERT_TX_SUCCESS:
        Serial.println("\nAlert: The Transmission was successful.");
        Serial.printf("TX buffered: %d\t", twai_status_info.msgs_to_tx);
        break;
    case TWAI_ALERT_RX_QUEUE_FULL:
        Serial.println("\nAlert: The RX queue is full causing a received frame to be lost.");
        Serial.printf("RX buffered: %d\t", twai_status_info.msgs_to_rx);
        Serial.printf("RX missed: %d\t", twai_status_info.rx_missed_count);
        Serial.printf("RX overrun %d\n", twai_status_info.rx_overrun_count);
        delay(1000);
        break;

    default:
        break;
    }

    switch (twai_status_info.state)
    {
    case TWAI_STATE_RUNNING:
        Serial.println("\nTWAI_STATE_RUNNING");
        break;
    case TWAI_STATE_BUS_OFF:
        Serial.println("\nTWAI_STATE_BUS_OFF");
        twai_initiate_recovery();
        delay(1000);
        break;
    case TWAI_STATE_STOPPED:
        Serial.println("\nTWAI_STATE_STOPPED");
        twai_start();
        delay(1000);
        break;
    case TWAI_STATE_RECOVERING:
        Serial.println("\nTWAI_STATE_RECOVERING");
        delay(1000);
        break;

    default:
        break;
    }

    // 如果TWAI有信息接收到
    if (alerts_triggered & TWAI_ALERT_RX_DATA)
    {
        twai_message_t rx_buf;
        while (twai_receive(&rx_buf, 0) == ESP_OK)
        {
            Twai_Receive_Message(rx_buf);
        }
    }
}

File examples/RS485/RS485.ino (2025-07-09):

#include <Arduino.h>
#include <HardwareSerial.h>
#include "pin_config.h"

// RS485
#define RS485_TX 22
#define RS485_RX 21
#define RS485_RE_PIN 17   //MAX13487E RE pin
#define RS485_SHUTDOWN_PIN 19 //MAX13487E shutdown pin
// WS2812B
#define WS2812B_DATA 4
// CAN
#define CAN_TX 27
#define CAN_RX 26
// RS485 and CAN Boost power supply
#define BOOST_ENABLE_PIN 16
//SD
#define SD_MISO 2
#define SD_MOSI 15
#define SD_SCLK 14
#define SD_CS 13

#define RS485 Serial1 

void setup()
{
    Serial.begin(115200);

    // enable boost power chip
    pinMode(BOOST_ENABLE_PIN, OUTPUT);
    digitalWrite(BOOST_ENABLE_PIN, HIGH);

    pinMode(RS485_RE_PIN, OUTPUT);  
    pinMode(RS485_SHUTDOWN_PIN, OUTPUT);  

    digitalWrite(RS485_SHUTDOWN_PIN, HIGH); // Shutdown Disable , 1:Enable RS485 , 0:Disable RS485
    digitalWrite(RS485_RE_PIN, HIGH);       // Receive Enable

    RS485.begin(115200, SERIAL_8N1, RS485_RX, RS485_TX);

}

void loop()
{
    uint8_t request[] = {0x01, 0x03, 0x00, 0x00, 0x00, 0x04, 0x44, 0x09};
    delay(10);
    RS485.write(request, sizeof(request));
    RS485.flush();
    delay(100);
    uint8_t response[20];
    int index = 0;
    unsigned long startTime = millis();
    while ((millis() - startTime) < 500) {
        if (RS485.available()) {
            response[index++] = RS485.read();
            if (index >= sizeof(response)) break;
        }
    }

    Serial.print("Raw Modbus response: ");
    for (int i = 0; i < index; i++) {
        Serial.printf("%02X ", response[i]);
    }
    Serial.println();
}

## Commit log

2022-09-05 add Arduino setting
2022-11-14 Dimension file upload
    [T-CAN485.DXF]
2024-06-24 Update Arduino_esp32_v3.0.1 version
    [T-CAN485.DXF]
2026-01-19 Added dwg
    [T-CAN485.dwg]
2026-09-22 Update the voltage range image.
